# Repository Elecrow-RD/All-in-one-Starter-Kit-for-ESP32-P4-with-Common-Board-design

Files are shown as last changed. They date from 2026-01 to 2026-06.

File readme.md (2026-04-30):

### 1, Product picture



### 2, Product version number

| | Hardware | Software | Remark |
| ---- | --- | --- | --- |
| 1 | V1.0 | V1.0 | old |
| 2 | V1.1 | V1.1 | latest |

Differences between versions:

**V1.0**: This version uses a 360° servo.

**V1.1**: This version uses a 180° servo.

Use the corresponding code in Lesson 8.

### 3, product information

| Main Processor（ESP32-P4） | |
| --- | --- |
| CPU/SoC | 32-bit RISC-V dual-core processor up to 360 MHz for HP system;32-bit RISC-V single-core processor up to 40 MHz for LP system |
| System Memory | 16 MB (OPI/HPI)³  in-Package PSRAM |
| Storage | 128 KB HP ROM、16 KB LP ROM |
| Development language | C/C++ Language |
| **Display** | |
| Size | 7inch |
| Resolution | 1024*600 |
| Touch Type | Capacitive |
| Panel Type | IPS |
| **Wireless Communication** | |
| Bluetooth | Not supported |
| WiFi | Not supported |
| Wireless communication expansion | Support can be used with [wireless module](https://www.elecrow.com/wireless-module-for-crowpanel-advanced-series.html) |
| Camera | 2 MegaPixels,100° wide-angle |
| **Hardware** | |
| Interface | 1x TYPE-C Interface,1x I/C(ZX-HY2.0-4PZZ), 1x UART(ZX-HY2.0-4PZZ), 1xI/O(20P*2,P=2.54mm), 1xCSI, 1xUSB, 1x Ethernet,1x TF Card Slot |
| Button | Rest Button |
| LED Indicator | I/O port working status indicator light |
| **Other** | |
| Size | 195\*170*46（mm） |
| Material | PP Plastic |
| Input | 5v |
| Weight | 600g |

### 4, Use the driver module

| Name | dependency library |
| ---- | --- |
| LVGL | lvgl/lvgl@8.3.3 |

### 5,Quick Start
##### Arduino IDE starts

1.Download the library files used by this product to the 'libraries' folder.

C:\Users\Documents\Arduino\libraries\



2.Open the Arduino IDE

7739691367693(1)

3.Open the code configuration environment and burn it



##### ESP-IDF starts

1.Right-click on an empty space in the project folder and select "Open with VS Code" to open the project.


2.In the IDF plug-in, select the port, then compile and flash



### 6,Folder structure.
|--3D file： Contains 3D model files (.stp) for the hardware. These files can be used for visualization, enclosure design, or integration into CAD software.

|--Datasheet: Includes datasheets for components used in the project, providing detailed specifications, electrical characteristics, and pin configurations.

|--Eagle_SCH&PCB: Contains **Eagle CAD** schematic (`.sch`) and PCB layout (`.brd`) files. These are used for circuit design and PCB manufacturing.

|--example: Provides example code and projects to demonstrate how to use the hardware and libraries. These examples help users get started quickly.

|--factory_firmware: Stores pre-compiled factory firmware that can be directly flashed onto the device. This ensures the device runs the default functionality.

|--factory_sourcecode:  Contains the source code for the factory firmware, allowing users to modify and rebuild the firmware as needed.

|--libraries: Includes necessary libraries required for compiling and running the project. These libraries provide drivers and additional functionalities for the hardware.

### 7,Pin definition
1，Ultrasonic Sensor：



2，LIGHT SENSOR



3，LED



4,Temperature & Humidity(DHT20)



5,DSI



6.PIR

IO24；

7.Servo Motor

IO25;

8,Accelerometer & Gyro



9,HALL SENSOR

IO7;

10,Custom key

IO16;



11,Touch Sensor

IO2;

12,MIC



13,Audio Interface



14,GAS-MQ2

IO17;

15,Relay

IO42;

16,CSI Interface



17,Wireless module



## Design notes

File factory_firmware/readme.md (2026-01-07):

# How to install the factory demo firmware with flash download tool?

#### 1.Preparation:

- USB C cable
- Laptop/PC
- Crowpanel Advance HMI ESP32 AI Display
- Flash download tool

Check whether the materials on the PCBA board are defective. Such as less material, false welding, tin and other bad phenomena.

#### 2.Flash the firmware 

##### Step1 Connect the ESP32 P4 to the laptop/PC with USB-C cable. The power indicator will light up.

##### Step2 Open the flash download tool. 

flash02

For the  Crowpanel Advance HMI ESP32 AI Display, the chip select ESP32-P4:



##### Step3

①Choose the firmware files;

②Enter the address: 

bootloader-0x2000.bin-------0x2000

esp32p4_dev_kits_ui-0x10000.bin----0x10000

partition-table-0x8000.bin-----0x8000

storage-0x910000.bin-------0x910000

③Check the firmware files;

④Select the correct port number;

⑤Click “Start” to download

##### Step5 After the download is complete, blue FINISH will be displayed, and the progress bar at the bottom shows that it has come to an end.

##### Step6 Press the reset button to show the demo.

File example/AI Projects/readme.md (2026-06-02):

All-in-one_Starter_Kit_for_ESP32-P4_AI Demo User Guide
Preparation tools:
All-in-one Starter Kit for ESP32-P4 with Common Board



Wireless Module ESP32-C6:



USB cable:



VS Code (ESP-IDF v5.5.3 installed)



Download the code for the P4 kit:
Download the code for the corresponding screen size:

https://github.com/Elecrow-RD/All-in-one-Starter-Kit-for-ESP32-P4-with-Common-Board-design/tree/master/example/AI%20Projects/ESP-IDF_Code

Use VS Code to open the project:
1. Open VS Code and choose to open the project folder.



2. Select the folder you want to open, click “Select Folder” to open the project. Be careful not to double-click to open it.



3. Connect the device to the computer. Connect the device side to the UART0 port and plug it into the computer’s COM port.



4. Select ESP-IDF v5.4.2.



5. Select the flashing method.



6. Select the COM port.



7. Select the flashing development board – esp32p4.



8.Before flashing, you can choose to clear the previous “build” cache. This step is not necessary, but you can choose to clear it. If you have modified the code, clearing the previous cache will improve the compilation success rate.



9. Compile the project. Please make sure the network connection is good. The compilation process may take some time, so please wait patiently.



This means the compilation is successful:



10. Click to flash to the P4 HMI development board.



Once the download is complete, start configuring the **Wi-Fi**:



① Connect your phone to the Wi-Fi network named “Xiaozhi-A0B5.” You will be automatically redirected to the Wi-Fi settings page. Enter the password for the Wi-Fi network you want to connect to, tap “Connect,” and the Wi-Fi setup is complete.



② A message indicating that the configuration was successful will appear.



11. After flashing is completed, when the device connects to Wi-Fi, the screen will display the verification code for connecting the device:



12. On the computer, log in to the “xiaozhi.me” website to configure the device, and first set it to the English version.



13. Click “Console” to enter the console.



14. Click “Add Device” to add a device.



15. Enter the device code, then click “Confirm”. Note that the device code here must be based on the output displayed on your own device.



16. Select “Open Source” and click “Start Using”.



17. Now your AI device can already chat. Since the default language is Chinese, we also need to configure the role. Click “Configure Role”.



18. Set “Dialogue Language” to “English”.



19. Save the configuration.



20. Next, we set the wake word. First, go back to “Agents”.



21. Select “Manage Devices”.



22. Select “Customize”, then choose “English”, and click “Next” to enter the next configuration step.



23. In “Select Wake Word”, choose your wake word, or you can select “No Wake Word” if you do not want a wake word.
Note: Here you can also choose to customize the emojis you need by selecting “Emoji Collection”. Otherwise, there will be no emojis. You also need to select a preset font; otherwise, the dialogue text will not be fully displayed.



24. After selecting, click “Next”.



25. Click “Generate assets.bin”.



26. Start Generate.



27. Click “Flash to Device Online” to perform the remote update. After the update is completed, you can use the new wake word to wake up the device.



28. During the update process, please do not disconnect the device from power or the network.



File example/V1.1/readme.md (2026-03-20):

## IDF

**Note**: This is an IDF course. Before proceeding, ensure you have **Visual Studio Code** and the **IDF **environment installed. The IDF version must be **5.4.2** or higher.

## Arduino

**Note**: In this Arduino example, the ESP32 is running **version 3.3.3**, and the library versions used are as follows:

ESP32Servo 3.1.3
ESP32_Display_panel 1.0.4
ESP32_IO_Expander 1.1.1
esp-lib-utils 0.3.0
ESP32_Display_panel 1.0.4
HCSR04 2.0.0
Adafruit_BusIO 1.17.4
lvgl 8.3.11
Adafruit NeoPixel 1.15.1

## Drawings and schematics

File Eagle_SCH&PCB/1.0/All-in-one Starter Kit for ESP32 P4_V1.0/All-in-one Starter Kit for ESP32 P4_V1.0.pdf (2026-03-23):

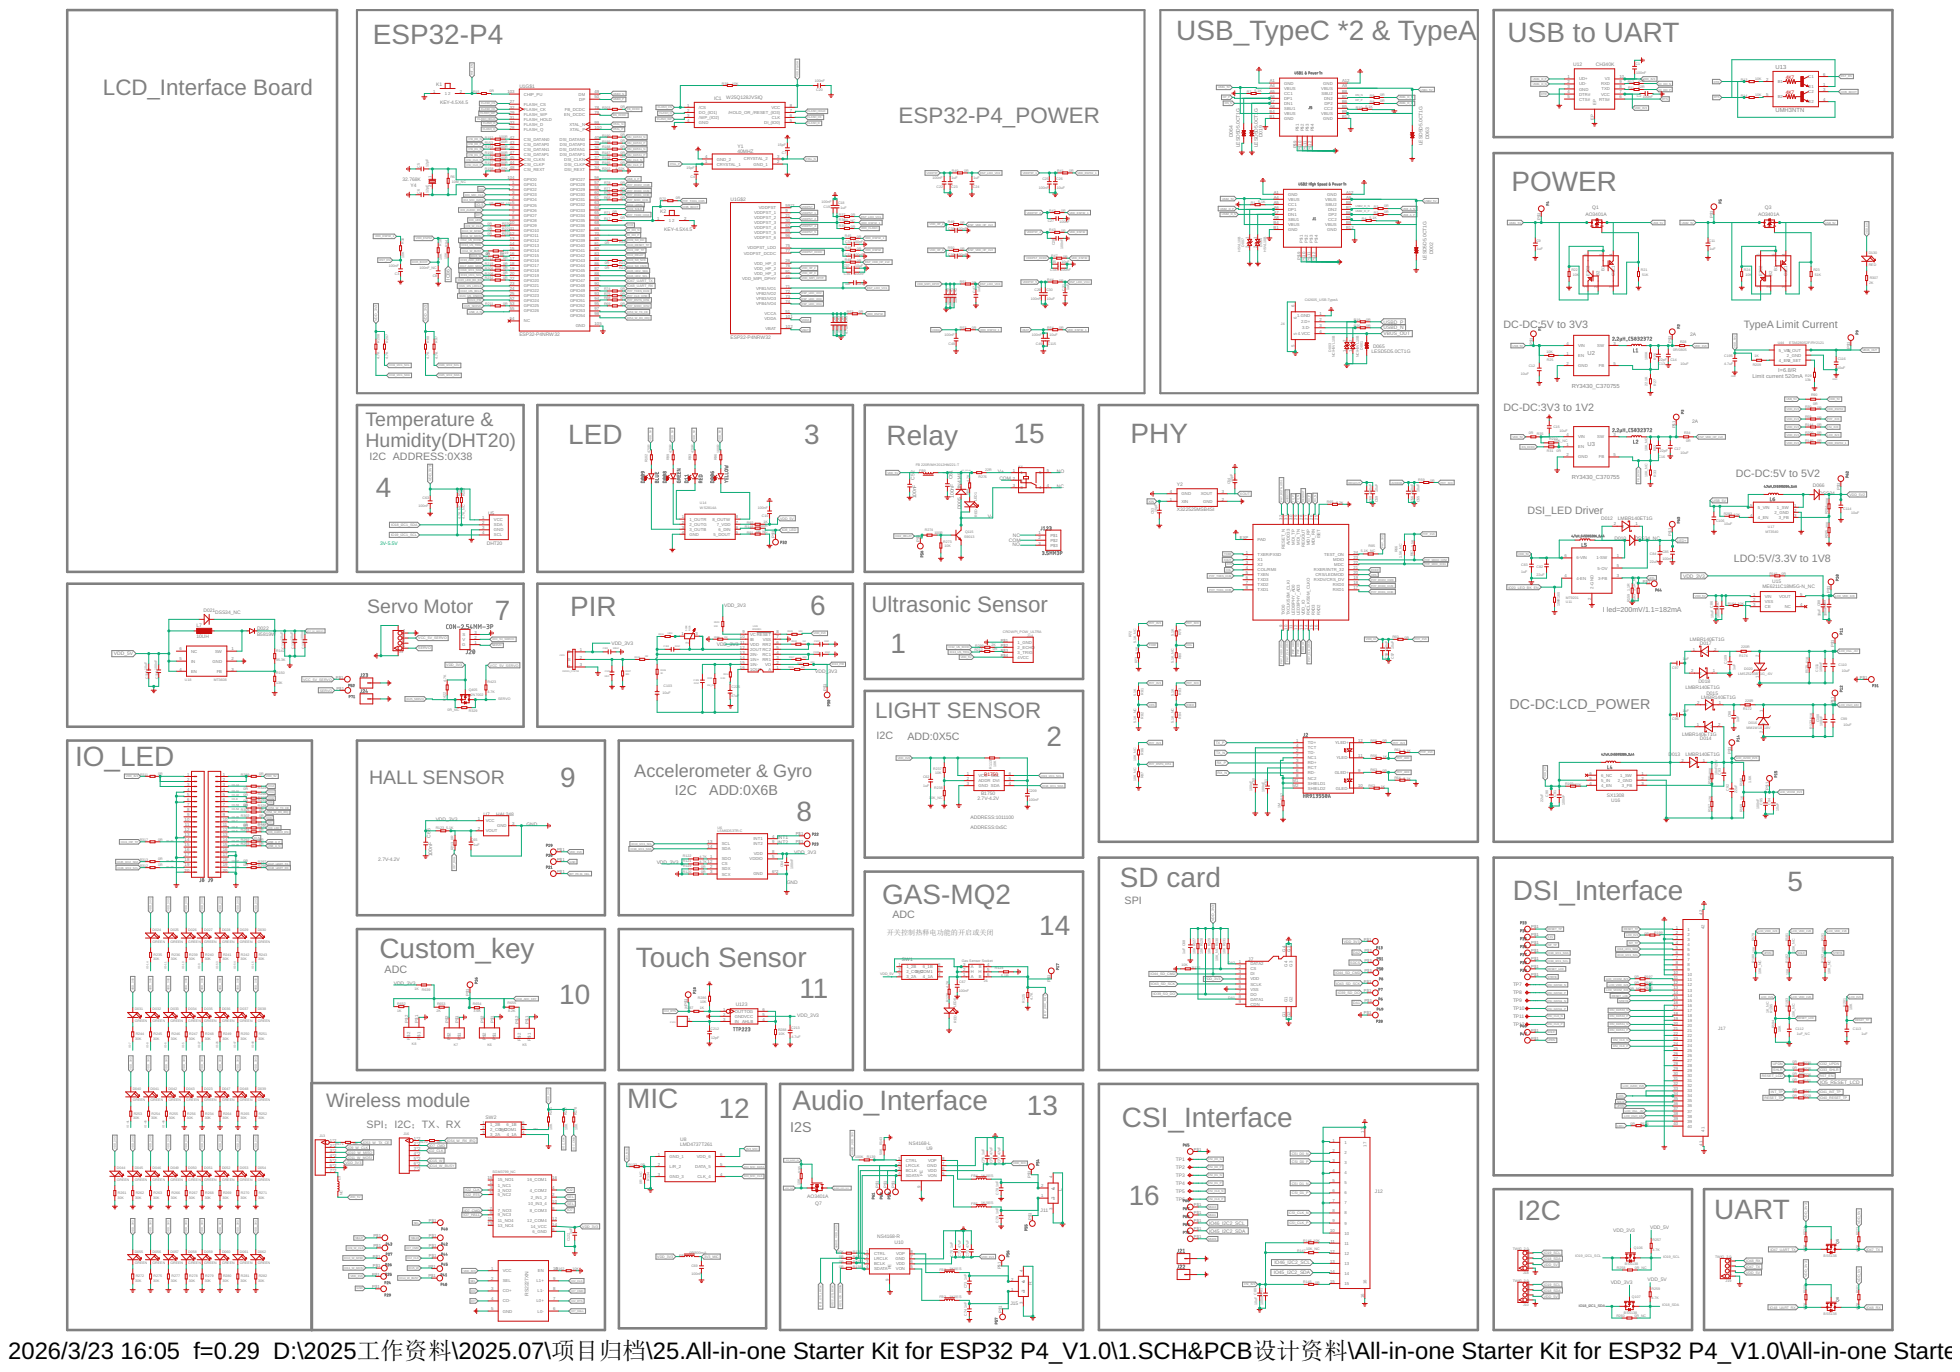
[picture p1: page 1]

2026/3/23 16:05 f=0.29 D:\2025工作资料\2025.07\项目归档\25.All-in-one Starter Kit for ESP32 P4_V1.0\1.SCH&PCB设计资料\All-in-one Starter Kit for ESP32 P4_V1.0\All-in-one Starter Kit for ESP32 P4_V1.0.sch (Sheet: 1/1)

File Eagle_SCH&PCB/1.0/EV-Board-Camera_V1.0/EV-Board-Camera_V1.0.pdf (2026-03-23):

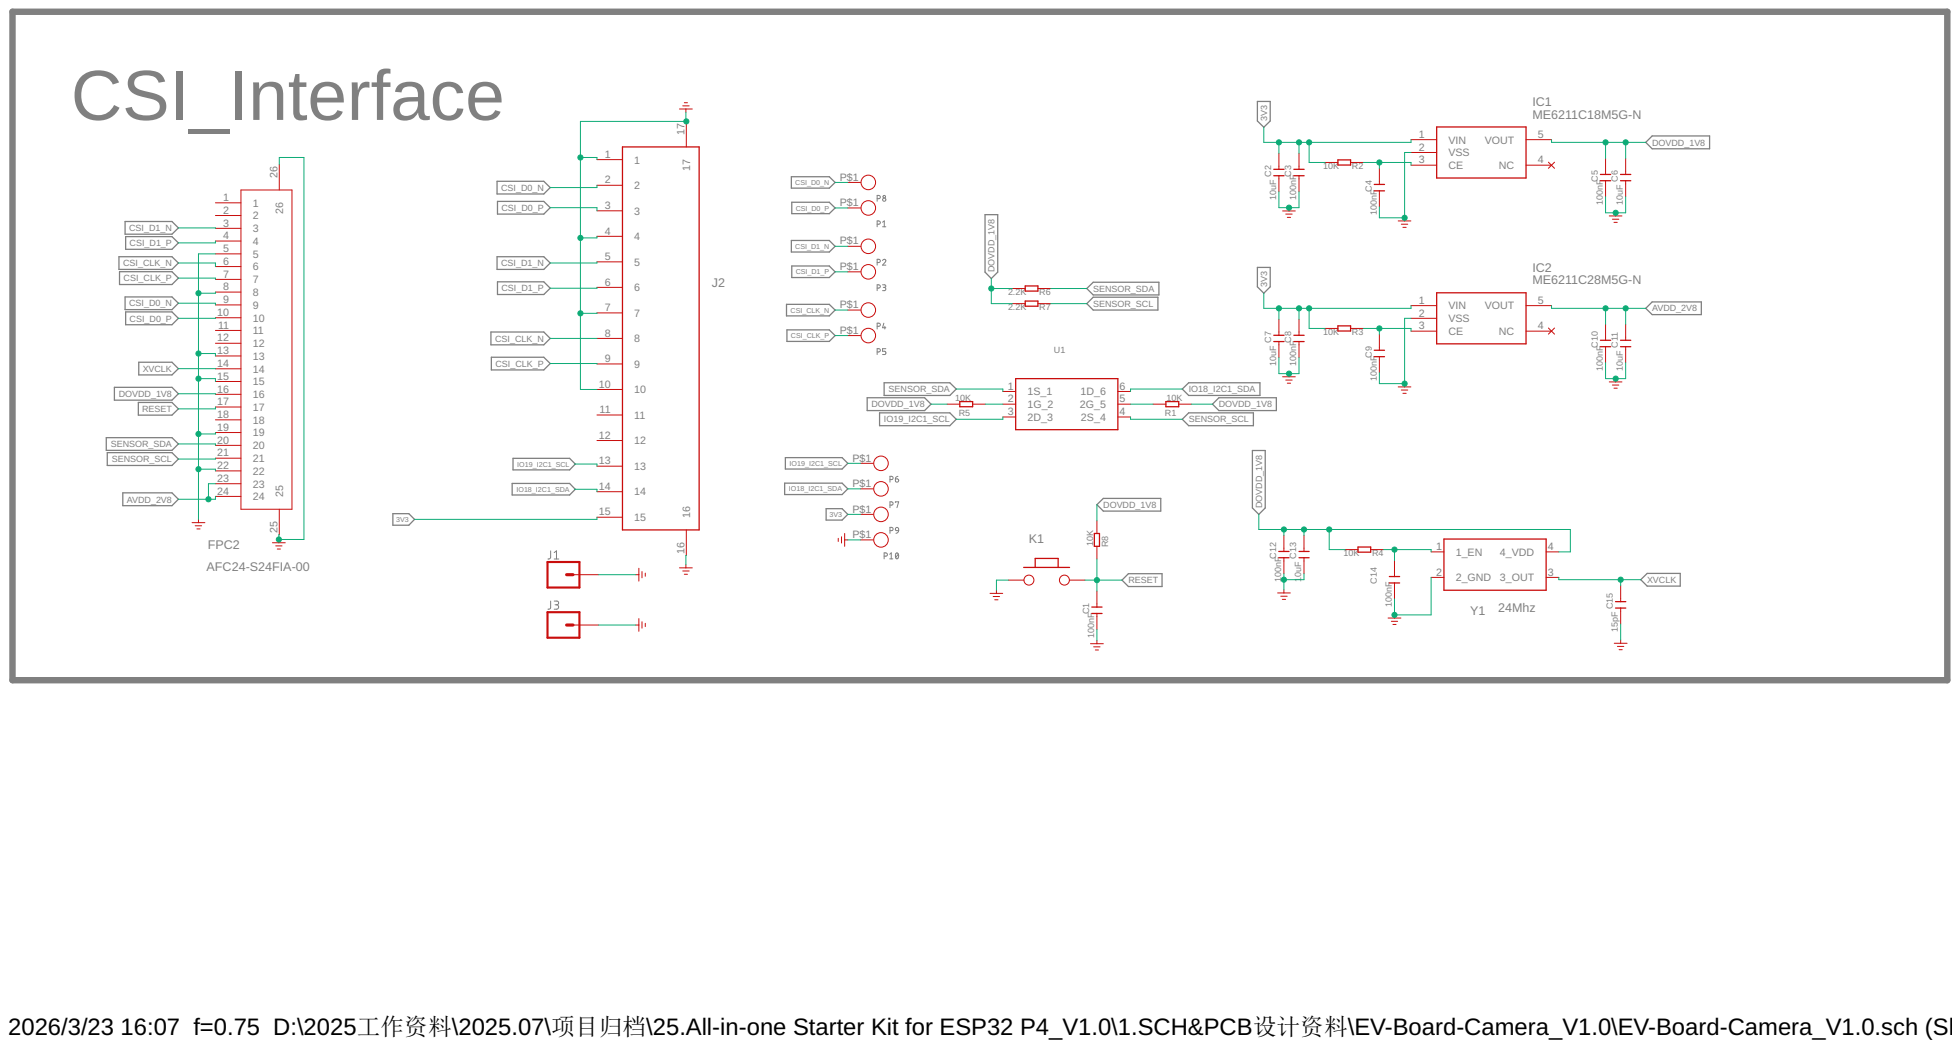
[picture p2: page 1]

2026/3/23 16:07 f=0.75 D:\2025工作资料\2025.07\项目归档\25.All-in-one Starter Kit for ESP32 P4_V1.0\1.SCH&PCB设计资料\EV-Board-Camera_V1.0\EV-Board-Camera_V1.0.sch (Sheet: 1/1)

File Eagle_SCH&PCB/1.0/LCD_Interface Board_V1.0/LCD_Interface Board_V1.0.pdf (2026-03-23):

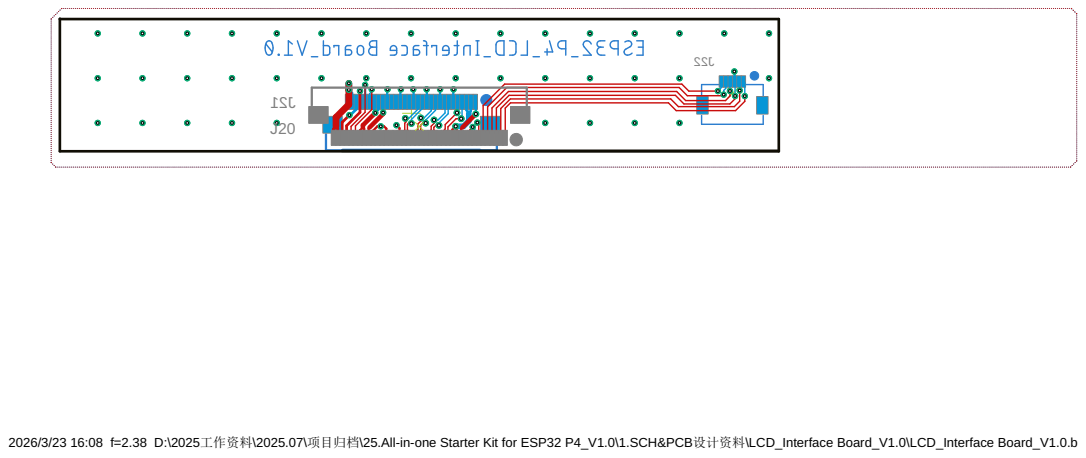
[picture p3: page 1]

2026/3/23 16:08 f=2.38 D:\2025工作资料\2025.07\项目归档\25.All-in-one Starter Kit for ESP32 P4_V1.0\1.SCH&PCB设计资料\LCD_Interface Board_V1.0\LCD_Interface Board_V1.0.brd

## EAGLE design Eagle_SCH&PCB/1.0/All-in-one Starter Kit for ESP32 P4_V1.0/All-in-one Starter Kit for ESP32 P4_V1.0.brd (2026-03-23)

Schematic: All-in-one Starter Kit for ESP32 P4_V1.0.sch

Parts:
C1, C2, C3, C10, C19, C20, C22, C25, C27, C28, C29, C32, C33, C34, C36, C38, C39, C41, C44, C46, C48, C49, C50, C51, C52, C56, C58, C60, C61, C63, C64, C66, C67, C69, C81, C85, C87, C89, C91, C95, C100, C102, C111, C118, C121, C209: 100nF; 0603
C4, C7: 15pF; 0603
C5, C6: 12pF; 0603
C8: 100nF_NC; 0603
C9, C11, C18, C21, C23, C24, C31, C42, C47, C65, C70, C75, C96, C97, C98, C109, C113, C122: 1uF; 0603
C12, C14, C15, C17, C26, C30, C35, C37, C55, C57, C59, C80, C86, C88, C94, C99, C103, C106, C110, C114, C115, C116: 10uF; 0603
C13, C16: 22pF; 0603
C40, C43: 10nF; 0603
C45, C195, C213: 4.7uF; 0603
C53, C54: 15pF; C0603
C62, C68, C83: 1uF; C0603
C71, C72, C76, C77: 47uF; 0603
C73, C74, C78, C79: 1nF; 0603
C82, C84, C90, C92: 22uF; C0805
C93: 10nF/25V; 0603
C101, C107, C108: 10nF; C0603
C104, C105: 22nF; C0603
C112: 1uF_NC; 0603
C117, C119, C120: 10uF; C0603
C212: 12pF; C0603
C225: 47uF; C0805
D001, D003: NC/H5VL10B; H5VL10B
D002, D019, D063, D064, D065: LESD5D5.0CT1G; TVS_LESD5D5.0CT1G
D004, D007: H5VL10B
D005: 1N4148; D_SOD123
D006: YELLOW; LED-8MM
D008: GREEN; LED-8MM
D009: BLUE; LED-8MM
D010, D021: DSS34_NC; D_SOD123FL
D11: RED; LED-8MM
D012, D013, D014, D015, D017, D018: LMBR140ET1G
D016: MM1W18_18V; LMSZ5233BT1G
D020: LMSZ5233BT1G_-6V; LMSZ5233BT1G
D022: B5819W; SOD-123_MINI-SMA
D023, D024, D025, D026, D027, D028, D029, D030, D031, D032, D033, D034, D035, D036, D037, D038, D039, D040, D041, D042, D043, D044, D045, D046, D047, D048, D049, D050, D051, D052, D053, D054, D055, D056, D057, D058, D059, D060, D061, D062: GREEN; LED_0603_SMT
D066: DSS34; D_SOD123FL
D130: RED; LED_0603_SMT
FB1: 0R/800mA; L0603
FB2, FB3, FB4, FB5: 1K/磁珠; L0603
FB9: FB 220R/MH2012HM221-T; L0805
IC1: W25Q128JVSIQ; SOIC127P790X216-8N
J1: USB2 High Speed & Power in; WZ3532R024-ESP32-V0.1-20221226_KEVIN_3.0TYPEC-SMD
J2: HR913550A; LORA_BASIC_GATEWAY_-MODULE_HR911105A-RJ45
J3: A_XBJ_CONNECTOR_TWIG-4P-2.0-SMD-FEMALE-REINFORCE9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; A_XBJ_CONNECTOR_4P-SMD-2.0-90D
J4: C42605_USB-TypeA; C42605/USB2.0
J5: USB1 & Power in; WZ3532R024-ESP32-V0.1-20221226_KEVIN_3.0TYPEC-SMD
J6: Gas Sensor Socket; MQ2
J7: HOLDER-MICROSD-9P; 9P-SMD-W/-RING
J8, J9: CONN_20; 1X20
J10, J18, J19: TWIG_2.0; 2.0_1X4
J11: L; 1X02L
J12: C262349_15P_1MM_下接_AFA07-S15FCC-00
J13, J16: HEADER-7P-18.28X2.5; H7-2.54-18.28X2.5X5MM
J14: CROWPI_POW_ULTRA
J15: R; 1X02L
J17: C19273935_40P_0.5MM_下接_HC-FPC-0.5-40P-FH20
J20: CON-2.54MM-3P; CON-PZ-2.54MM-1*3P-WT
J21, J22: CONN_01_3.1MM_SMD1X01_3.1MM_SMD; 1X01_2MM
J23, J24: CONN_01_2.6MM1X01_2.6-4MM; 1X01_2.6MM
J101: D203S_C78793; 3P-D8.1MM
J123: 3.5MM3P; 3.5MM*3P
K1, K2: KEY-4.5X4.5; KEY-4.5X4.5-SMD
K4: RELAY-SRD; REY5-6-19.1X15.5X15.3MM
K5, K6, K7, K8: BUTTON_2P
L1, L2: 2.2μH_C5832372; 1008(2520)
L3: NC; L0603
L4, L5, L6: 4.7uH_C45385206_2.4A; 1008(2520)
L7: 10UH; SMD-4X4MM
LED1, LED6: RED; DISCRETE_LED-0603
P1, P2, P3, P4, P5, P6, P7, P8, P9, P10, P11, P12, P13, P14, P15, P16, P17, P18, P19, P20, P21, P22, P23, P24, P25, P26, P27, P28, P29, P30, P31, P32, P33, P34, P35, P36, P37, P38, P39, P40, P41, P42, P43, P44, P45, P46, P47, P48, P49, P50, P51, P52, P54, P55, P56, P57, P58, P59, P60, P61, P62, P63, P64, P65, P66, P67, P68, P69, P70, P71: TEST_PADPAD-1.5MM; TEST_PAD-1.5MM
P101: KEY; 1P-D450
Q1, Q3, Q7: AO3401A; SOT23-3
Q2, Q4: LMBT3906DW1T1G
Q5, Q6, Q106, Q107: BSS138; SOT23
Q115: S9013; SOT23@1
Q405: 2N7002; SOT23
R1, R4, R7, R10, R61, R64, R73, R79, R81, R83, R123: 5.1K; R0603
R2, R3, R5, R8, R9, R15, R17, R19, R20, R30, R31, R34, R35, R37, R39, R40, R41, R42, R43, R44, R45, R46, R47, R48, R49, R50, R51, R52, R53, R54, R55, R58, R59, R60, R63, R68, R69, R70, R71, R74, R75, R76, R77, R78, R88, R118, R119, R120, R133, R140, R141, R144, R145, R151, R176, R185, R186, R187, R188, R189, R190, R196, R197, R199, R200, R203, R205, R206, R211, R212, R213, R214, R215, R216, R217, R219, R220, R221, R222, R225, R227, R228, R230, R231, R232, R289, R290, R291, R292, R293, R294, R295, R296, R297, R298, R302, R305, R311, R312, R313, R315, R317, R324, R328, R332: 0R; R0603
R6: 10M_NC; R0603
R11, R12, R276: 22R; R0603
R13, R14, R16, R18, R22, R24, R25, R38, R94, R95, R107, R109, R112, R113, R115, R117, R146, R149, R161, R162, R164, R177, R178, R179, R182, R191, R194, R201, R237, R273, R283, R286, R288: 10K; R0603
R21, R23, R173, R175: 51K; R0603
R26, R165, R284: 100K; R0603
R27: 22.1K; R0603
R28: 0R/0805; R0805-SP
R29: 13k; R0603
R32, R33, R86, R87, R147, R180, R181, R192, R193, R210, R238: 10K_NC; R0603
R36, R91, R134, R198, R226, R258, R260, R329: 0R_NC; R0603
R56, R62, R92, R106, R169, R209, R287, R639, R652: 1K; R0603
R57, R108, R110: 1M; R0603
R65: 6.2K; R0603
R66: 1.5K_NC; R0603
R67: 1.5K; R0603
R72, R80, R82, R84, R85: 5.1K_NC; R0603
R89, R97, R98, R121, R122, R125, R126, R207, R208, R257, R259, R422, R423: 4.7K; R0603
R90: 0R; R0805-SP
R93, R99, R102: 470R; R0603
R96, R148, R152, R153, R154, R155, R156, R157, R274: 100R; R0603
R100, R101, R223, R224: 4.7K; R0603-SP
R103, R104: 4.7K_NC; R0603
R105: 500K; 3P-SMD-SQUA-3.6X3.3
R111: 1M_1%; R0603
R114: 3.3K; R0603
R116: 130K; R0603
R124: 5.1R; R0603
R127, R128, R129, R131, R132, R160: 10K; R0603-SP
R130: 10K_NC; R0603-SP
R135, R139: 100K; R0603-SP
R136, R137, R138, R170, R171: 0R; R0603-SP
R142: 95.3K; R0603
R143: 50K; R0603-SP
R150: 13K; R0603
R158, R202: 4.02K; R0603
R159: 1.1R; R0603-SP
R163: 1.1R_NC; R0603-SP
R166: 180K; R0603
R167: 12K; R0603
R168: 1.6K; R0603
R172, R174: 220R; R0603
R195: 1K_NC; R0603
R234, R235, R236, R239, R240, R241, R242, R243, R244, R245, R246, R247, R248, R249, R250, R251, R252, R253, R254, R255, R256, R261, R262, R263, R264, R265, R266, R267, R268, R269, R270, R271, R272, R275, R277, R278, R279, R280, R281, R282, R285: 30K; R0603
R299, R307, R653: 2K; R0603
R654: 3.6K; R0603
R655: 8.2K; R0603
SW1, SW2: switch_6pin; SWITCH_6PIN_2P
TP1, TP2, TP3, TP4, TP5, TP6, TP7, TP8, TP9, TP10, TP11, TP12: TPTP08R; TP08R
U1: ESP32-P4NRW32; IC_ESP32-P4NRW32
U2, U3: RY3430_C370755; SOT95P280X145-5N
U4: IP101GR; QFN32_4X4
U5: DHT20; CROWTAIL-DHT20-V1.0-20211013_DHT20
U6: LSM6DS3TR-C; LGA-14L
U7: HAL248; SOT-23W
U8: LMD4737T261; MIC_LMD4737T261
U9: NS4168-L; NS4168-ESOP-8
U10: NS4168-R; NS4168-ESOP-8
U11: MT9201; COOPER_SOT23-6
U12: CH340K; ESOP-10-EP-150MIL
U13: UMH3NTN; SOP65P210X100-6N
U14: WS2814A
U15: ME6211C18M5G-N_NC; SOT95P282X145-5N
U16: SX1308; SOT95P280X145-6N
U17: MT3540; SOT95P280X145-5N
U18: MT3608; DBV_R-PDSO-G6
U19: SGM3799_NC; IC_SGM3799_TQFN2.6X1.8_16L
U44: ETA6280S2F/RY2121; IC_SOT23-5
U101: BIS0001; SOP16
U121: BH1750; B1750
U123: TTP223; SOT23-6L
U$196: MSOP10
Y1: 40MHZ; X322540MPB4SI
Y2: X322525MSB4SI; SMD3225
Y4: 32.768K; NORDIC_NRF_XTAL_3215_N

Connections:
3.3V: J17.2, P34.P$1, R199.2
3V3_MIC: C69.2, FB1.2, R133.1, U8.6 (VDD_6)
+5V_SYS_GAS: C67.2, J6.1 (A), J6.2 (H), J6.3 (A), R126.2, SW1.2 (2_COM2)
AUDIO_VDD_3V3: Q7.3 (3_D), R135.2, R139.2
AVDD33: C55.2, C56.2, R59.1, U4.31 (AVDD33)
BIT_P0.31_HAL: C65.1, P21.P$1, R123.1, R213.1, U7.2 (VOUT)
CLK_N: R186.2, U1.37 (DSI_CLKN)
CLK_P: R185.2, U1.38 (DSI_CLKP)
COL: R79.1, R80.2, U4.4 (COL/RMII)
COM: J123.2, K4.2
CRS: R81.1, R82.2, U4.20 (CRS/LEDMOD)
CSICLK_N: R156.1, U1.45 (CSI_CLKN)
CSICLK_P: R157.1, U1.44 (CSI_CLKP)
CSID0_N: R152.1, U1.42 (CSI_DATAN0)
CSID0_P: R153.1, U1.43 (CSI_DATAP0)
CSID1_N: R154.1, U1.46 (CSI_DATAN1)
CSID1_P: R155.1, U1.47 (CSI_DATAP1)
CSI_3V3: C80.1, C81.1, R144.2, R145.1, R146.1, R147.1
CSI_CLK_N: J12.8, R156.2, TP5.TP
CSI_CLK_P: J12.9, R157.2, TP6.TP
CSI_D0_N: J12.2, R152.2, TP1.TP
CSI_D0_P: J12.3, R153.2, TP2.TP
CSI_D1_N: J12.5, R154.2, TP3.TP
CSI_D1_P: J12.6, R155.2, TP4.TP
DA1: J7.8 (DATA1), P49.P$1, R127.1
DA2: J7.1 (DATA2), P51.P$1, R131.1
DATA0_N: R190.2, U1.40 (DSI_DATAN0)
DATA0_P: R189.2, U1.39 (DSI_DATAP0)
DATA1_N: R188.2, U1.36 (DSI_DATAN1)
DATA1_P: R187.2, U1.35 (DSI_DATAP1)
DN_N: D019.2, J5.A7 (DN1), J5.B7 (DN2), R9.2
DP_P: D064.2, J5.A6 (DP1), J5.B6 (DP2), R8.2
DSI_CLK_N: J17.23, R186.1, TP11.TP
DSI_CLK_P: J17.24, R185.1, TP12.TP
DSI_DATA0_N: J17.17, R190.1, TP7.TP
DSI_DATA0_P: J17.18, R189.1, TP8.TP
DSI_DATA1_N: J17.20, R188.1, TP9.TP
DSI_DATA1_P: J17.21, R187.1, TP10.TP
DTR: R13.2, U12.4 (DTR#), U13.4 (E2)
EN_DCDC: R31.2, U1.79 (EN_DCDC)
ESP_LDO_VO1: C21.2, R37.2, U1.71 (VFB1/VO1)
ESP_LDO_VO2: C24.1, R40.2, U1.72 (VFB2/VO2)
ESP_LDO_VO3: C47.2, R51.2, U1.73 (VFB3/VO3)
ESP_LDO_VO4: C31.2, R44.2, U1.74 (VFB4/VO4)
ESP_VDD_HP_1V2: R34.2, R48.2, R49.2, R50.2
FB_DCDC: C16.1, R32.2, R33.1, R203.1, U3.5 (FB)
FLASH_CK: IC1.6 (CLK), U1.32 (FLASH_CK)
FLASH_CS: IC1.1 (/CS), R38.1, U1.27 (FLASH_CS)
FLASH_D: IC1.5 (DI_(IO0)), U1.33 (FLASH_D)
FLASH_HOLD: IC1.7 (/HOLD_OR_/RESET_(IO3)), U1.31 (FLASH_HOLD)
FLASH_Q: IC1.2 (DO_(IO1)), U1.28 (FLASH_Q)
FLASH_WP: IC1.3 (/WP_(IO2)), U1.29 (FLASH_WP)
GND: C1.2, C2.1, C3.2, C4.2, C5.2, C6.2, C7.1, C8.2, C9.1, C10.1, C11.1, C12.2, C14.1, C15.2, C17.1, C18.2, C19.1, C20.2, C21.1, C22.2, C23.2, C24.2, C25.2, C26.1, C27.2, C28.2, C29.2, C30.1, C31.1, C32.2, C33.2, C34.2, C35.1, C36.2, C37.1, C38.2, C39.2, C40.2, C41.2, C42.2, C43.2, C44.2, C45.2, C46.2, C47.1, C48.2, C49.2, C50.1, C51.1, C52.1, C53.2, C54.1, C55.1, C56.1, C57.1, C58.1, C59.1, C60.1, C61.1, C62.1, C63.1, C64.1, C65.2, C66.1, C67.1, C68.1, C69.1, C70.2, C71.2, C72.2, C73.1, C74.1, C75.2, C76.2, C77.2, C78.1, C79.1, C80.2, C81.2, C82.2, C83.1, C84.2, C85.1, C86.2, C87.2, C88.2, C89.2, C90.2, C91.2, C92.2, C94.2, C95.2, C98.2, C99.2, C100.2, C101.1, C102.1, C106.1, C107.2, C108.2, C109.2, C110.2, C111.2, C112.2, C113.2, C114.1, C115.2, C116.2, C117.1, C118.1, C119.1, C120.1, C121.1, C122.1, C195.2, C209.1, C212.1, C213.1, C225.1, D001.1, D002.1, D003.1, D004.2, D007.2, D016.2, D018.1, D019.1, D020.1, D063.1, D064.1, D065.1, IC1.4 (GND), J1.A1 (GND), J1.A12 (GND), J1.B1 (GND), J1.B12 (GND), J1.P$9, J1.P$10, J1.P$11, J1.P$12, J3.4, J3.SS1, J3.SS2, J4.1 (1.GND), J4.5, J4.6, J5.A1 (GND), J5.A12 (GND), J5.B1 (GND), J5.B12 (GND), J5.P$9, J5.P$10, J5.P$11, J5.P$12, J7.6 (VSS), J7.G1, J7.G2, J7.G3, J7.G4, J8.4, J8.5, J8.6, J8.13, J8.17, J8.20, J9.16, J9.17, J9.20, J10.1, J11.3, J11.4, J12.1, J12.4, J12.7, J12.10, J12.16, J12.17, J13.6, J13.6-6 (6), J14.P$1 (1_GND), J15.3, J15.4, J17.3, J17.7, J17.8, J17.9, J17.10, J17.16, J17.19, J17.22, J17.25, J17.28, J17.31, J17.41, J17.42, J18.1, J19.1, J20.3 (S), J21.1, J22.1, J23.1, J24.1, J101.3 (G), K1.1, K2.2, K5.P$1, K6.P$1, K7.P$1, K8.P$1, LED6.-, P20.P$1, P28.P$1, P29.P$1, P31.P$1, P65.P$1, Q115.2 (E), R1.2, R4.1, R7.2, R10.1, R21.1, R22.1, R23.1, R24.1, R27.2, R29.2, R33.2, R57.1, R62.2, R64.2, R65.2, R73.1, R80.1, R82.1, R84.1, R87.1, R91.1, R107.1, R108.1, R119.1, R120.1, R124.1, R125.2, R132.2, R134.1, R143.1, R150.2, R158.2, R159.1, R160.2, R162.1, R163.1, R167.1, R169.1, R173.1, R175.1, R180.1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
IN1: C212.2, P101.1, U123.3 (IN)
INT1: P22.P$1, U6.4 (INT1)
INT2: P23.P$1, U6.9 (INT2)
INT_TP: J17.4, P35.P$1, R227.2
IO2: U1.2 (GPIO2), U19.4 (4_COM2), U$196.3 (CO+)
IO2_CLK: J16.3, J16.3-3 (3), P45.P$1, R177.1, U19.3 (3_NO2), U$196.9 (L1+)
IO2_RTS: P18.P$1, R287.2, U19.5 (5_NC2), U$196.7 (L0+)
IO3_MIC_CLK: U1.3 (GPIO3), U8.4 (CLK_4)
IO4_MIC_DATA: U1.4 (GPIO4), U8.5 (DATA_5)
IO5_RESET_LCD: R151.1, R231.2, U1.5 (GPIO5)
IO6_AUDIO_EN: Q7.1 (1_G), R95.1, R294.1, U1.6 (GPIO6)
IO7: R315.2, U1.7 (GPIO7), U19.8 (8_COM3), U$196.4 (CO-)
IO7_CMD: J16.2, J16.2-2 (2), P44.P$1, R178.1, U19.7 (7_NO3), U$196.8 (L1-)
IO7_HALL: R213.2, U19.9 (9_NC3), U$196.6 (L0-)
IO8_LED: P32.P$1, R148.1, R290.2, U1.8 (GPIO8)
IO9: R220.2, R291.2, U1.10 (GPIO9)
IO9_W_CLK: J13.2, J13.2-2 (2), P27.P$1, R220.1
IO10: R221.2, R295.2, U1.11 (GPIO10)
IO10_W_MISO: J13.3, J13.3-3 (3), P26.P$1, R221.1
IO11: R222.2, R296.2, U1.12 (GPIO11)
IO11_W_MOSI: J13.4, J13.4-4 (4), P25.P$1, R222.1
IO12_US_ECHO: R299.2, U1.13 (GPIO12)
IO13_US_TRIG: R212.2, U1.14 (GPIO13)
IO14: R219.2, R324.2, U1.15 (GPIO14)
IO14_W_BUSY: J16.6, J16.6-6 (6), P40.P$1, R219.1
IO15: R5.2, R302.1, U1.16 (GPIO15)
IO15_W: J16.5, J16.5-5 (5), P41.P$1, R5.1
IO16_ADC_KEY: P16.P$1, R214.2, R639.2, R652.2, R653.2, R654.2, R655.2
IO17_ADC_MQ2: J6.4 (B), J6.6 (B), P17.P$1, R125.1, R215.2
IO18_I2C1_SDA: J17.5, P36.P$1, Q107.2 (S), R103.2, R205.2, R208.2, R260.1, U5.2 (SDA), U6.14 (SDA), U121.4 (SDA)
IO18_SDA: J10.3, J18.3, Q107.3 (D), R259.2, R260.2
IO19_I2C1_SCL: J17.6, P37.P$1, Q106.2 (S), R104.2, R206.2, R207.2, R258.1, U5.4 (SCL), U6.13 (SCL), U121.6 (SCL)
IO19_SCL: J10.4, J18.4, Q106.3 (D), R257.2, R258.2
IO20_LED_BK_EN: R160.1, R232.2, U11.4 (4-EN)
IO21_I2S_LRCLK: R136.2, U1.23 (GPIO21)
IO22_I2S_BCLK: R137.2, U1.24 (GPIO22)
IO23_I2S_DSDIN: R138.2, U1.25 (GPIO23)
IO24_PIR: P30.P$1, R112.1, U1.52 (GPIO24)
IO25_SERVO: Q405.2 (S), R211.2, R329.2, R422.1
IO32_UPDN: R230.1, U1.63 (GPIO32)
IO33_SHLR: R225.1, U1.64 (GPIO33)
IO35_BOOT: C8.1, K2.1, R17.1, R18.1, R70.2, U13.3 (C2)
IO36: R94.2, U1.68 (GPIO36)
IO39_SD_DO: J7.7 (DO), P6.P$1, R128.1, R332.2
IO40_RESET_TP: R228.1, U1.81 (GPIO40)
IO41_INT_TP: R227.1, R317.2, U1.82 (GPIO41)
IO42_RELAY: P58.P$1, R274.2, U1.83 (GPIO42)
IO43_SD_SCK: J7.5 (SCLK), P7.P$1, R217.2
IO44_SD_CMD: J7.3 (DI), P8.P$1, R129.1, R216.2
IO45_I2C2_SDA: J12.14, P69.P$1, R98.2, R313.2, U1.87 (GPIO45)
IO46_I2C2_SCL: J12.13, P68.P$1, R97.2, R312.2, U1.88 (GPIO46)
IO47_TX: J19.3, Q5.3 (D), R223.2
IO47_UART_TX: Q5.2 (S), R224.2, R297.2, U1.89 (GPIO47)
IO48_RX: J19.4, Q6.3 (D), R101.2
IO48_UART_RX: Q6.2 (S), R100.2, R298.2, U1.90 (GPIO48)
IO53_W_TX_CE: R171.2, R328.2, U1.97 (GPIO53)
IO54_W_RX_IRQ: R170.2, R305.1, U1.98 (GPIO54)
IO-5: J9.13, R231.1, R247.2
IO-6: J9.12, R246.2, R294.2
IO-7: J9.10, R244.2, R315.1
IO-8: J9.11, R245.2, R290.1
IO-9: J9.6, R240.2, R291.1
IO-10: J9.5, R239.2, R295.1
IO-11: J9.4, R236.2, R296.1
IO-14: J9.3, R235.2, R324.1
IO-15: J9.9, R243.2, R302.2
IO-26: J9.15, R249.2, R293.2
IO-27: J9.14, R248.2, R292.2
IO-41: J8.14, R253.2, R317.1
IO-45: J8.18, R254.2, R313.1
IO-46: J8.19, R255.2, R312.1
IO-47: J9.18, R250.2, R297.1
IO-48: J9.19, R251.2, R298.1
IO-53: J9.7, R241.2, R328.1
IO-54: J9.8, R242.2, R305.2
IOT_5V: J13.7, J13.7-7 (7), L3.1
IO_DO_N: R12.1, U1.69 (GPIO37)
IO_DO_P: R11.1, U1.70 (GPIO38)
LCD_3V3: R195.2, R199.1, R200.2, R201.2
LCD_AVDD_9V6: C92.1, C93.1, D013.1, D014.2, J17.32, P14.P$1, R166.2, R168.2
LCD_VCOM_3V3: C94.1, C95.1, P15.P$1, R168.1, R169.2, R197.1, R198.1
LCD_VDD_1V8: C88.1, C89.1, P10.P$1, R141.2, R179.2, R181.2, R191.2, R193.2, R196.1, U15.5 (VOUT)
LCD_VGH_18V: C99.1, C100.1, D016.1, J17.38, P12.P$1, R172.1, R173.2
LCD_VGL_-6V: C110.1, C111.1, D020.2, J17.37, P11.P$1, R174.1, R175.2
LED+: C84.1, C85.2, D010.-, D012.1, P63.P$1, R176.1, U11.5 (5-OV)
LED-: J17.33, J17.34, P64.P$1, R159.2, R163.2, U11.3 (3-FB)
unnamed: Q3.1 (1_G), Q4.3 (C1), R23.2
unnamed: C6.1, R6.1, U1.1 (GPIO1), Y4.2
unnamed: C5.1, R6.2, U1.104 (GPIO0), Y4.1
unnamed: Q1.1 (1_G), Q2.3 (C1), R21.2
unnamed: Q2.2 (B2), Q2.5 (B1), Q2.6 (C2), R22.2
unnamed: C43.1, C44.1, C45.1, C46.1, R52.1, U1.51 (VCCA)
unnamed: Q4.2 (B2), Q4.5 (B1), Q4.6 (C2), R24.2
unnamed: J1.B5 (CC2), R4.2
unnamed: J1.A5 (CC1), R1.1
unnamed: J5.A5 (CC1), R7.1
unnamed: R12.2, U12.9 (RXD)
unnamed: R11.2, U12.8 (TXD)
unnamed: R13.1, U13.2 (B1)
unnamed: R15.1, U1.103 (CHIP_PU)
unnamed: R14.1, U13.5 (B2)
unnamed: R17.2, U1.66 (GPIO35)
unnamed: D130.2 (2_K), R307.1
unnamed: R209.1, U44.4 (4_EN)
unnamed: J2.12 (YLED+), R55.1
unnamed: R25.1, U2.1 (EN)
unnamed: L1.1, U2.3 (SW)
unnamed: C13.2, C14.2, L1.2, P2.P$1, R26.1, R28.1
unnamed: C13.1, R26.2, R27.1, U2.5 (FB)
unnamed: R31.1, R210.2, U3.1 (EN)
unnamed: L2.1, U3.3 (SW)
unnamed: C16.2, C17.2, L2.2, P3.P$1, R32.1, R34.1
unnamed: R203.2, U1.78 (FB_DCDC)
unnamed: C15.1, R35.1, R210.1, U3.4 (VIN)
unnamed: C32.1, R45.1, U1.96 (VDDPST_6)
unnamed: J2.11 (YLED-), R56.1
unnamed: J2.7 (NC1), J2.8 (NC2), J2.M1 (SHIELD1), J2.M2 (SHIELD2), R57.2
unnamed: C50.2, J2.4 (TCT)
unnamed: R74.2, U1.92 (GPIO49)
unnamed: C51.2, J2.5 (RCT)
unnamed: R75.2, U1.93 (GPIO50)
unnamed: R77.2, U1.58 (GPIO29)
unnamed: R85.1, U4.24 (TEST_ON)
unnamed: R76.2, U1.60 (GPIO30)
unnamed: R71.2, U1.65 (GPIO34)
unnamed: R78.2, U1.57 (GPIO28)
unnamed: R88.2, U1.94 (GPIO51)
unnamed: J2.10 (GLED-), R62.1
unnamed: J2.9 (GLED+), R63.1
unnamed: R68.2, U1.61 (GPIO31)
unnamed: LED1.+, R89.1
unnamed: J14.P$3 (3_TRIG), R212.1
unnamed: R232.1, U1.22 (GPIO20)
unnamed: R214.1, U1.17 (GPIO16)
unnamed: C209.2, R113.1, U121.5 (DVI)
unnamed: R91.2, U14.5 (5_DOUT)
unnamed: R69.2, U1.95 (GPIO52)
unnamed: D009.2 (C), U14.3 (3_OUTB)
unnamed: D11.1 (A), R93.2
unnamed: R65.1, U4.25 (ISET)
unnamed: D008.2 (C), U14.2 (2_OUTG)
unnamed: D11.2 (C), U14.1 (1_OUTR)
unnamed: R29.1, U44.3 (3_SET)
unnamed: D006.1 (A), R96.2
unnamed: J5.B5 (CC2), R10.2
unnamed: D006.2 (C), U14.8 (8_OUTW)
unnamed: R142.2, R150.1, U18.3 (FB)
unnamed: D008.1 (A), R99.2
unnamed: R92.2, U14.7 (7_VDD)
unnamed: D022.A, L7.2, U18.1 (SW)
unnamed: D009.1 (A), R102.2
unnamed: R117.1, U101.3 (RR1)
unnamed: C108.1, R117.2, U101.4 (RC1)
unnamed: R112.2, U101.2 (VO)
unnamed: R110.2, U101.6 (RR2)
unnamed: C107.1, R110.1, U101.5 (RC2)
unnamed: C104.2, R105.2 (3), R105.3 (2), U101.12 (2OUT)
unnamed: C104.1, R106.2, R116.2, U101.13 (2IN-)
unnamed: R109.2, U101.9 (VC)
unnamed: R108.2, U101.10 (IB)
unnamed: C101.2, J101.2 (S), R107.2, R118.2
unnamed: C103.2, C105.1, R111.1, U101.16 (1OUT)
unnamed: C105.2, R111.2, R114.2, U101.15 (1IN-)
unnamed: C103.1, R106.1
unnamed: C225.2, R114.1
unnamed: R115.2, U101.1 (A)
unnamed: R118.1, U101.14 (1IN+)
unnamed: R105.1, R116.1
unnamed: R119.2, U6.2 (SDX)
unnamed: R120.2, U6.3 (SCX)
unnamed: R121.2, U6.12 (CS)
unnamed: R122.2, U6.1 (SDO)
unnamed: J6.5 (H), R124.2
unnamed: LED6.+, R126.1
unnamed: R217.1, U1.84 (GPIO43)
unnamed: R216.1, U1.86 (GPIO44)
unnamed: R133.2, R134.2, U8.2 (L/R_2)
unnamed: R135.1, U10.1 (CTRL)
unnamed: P61.P$1, R136.1, U9.2 (LRCLK), U10.2 (LRCLK)
unnamed: P60.P$1, R137.1, U9.3 (BCLK), U10.3 (BCLK)
unnamed: P59.P$1, R138.1, U9.4 (SDATA), U10.4 (SDATA)
unnamed: FB2.1, U10.8 (VOP)
unnamed: FB3.1, U10.5 (VON)
unnamed: R332.1, U1.80 (GPIO39)
unnamed: C78.2, FB4.2, J11.2, P54.P$1
unnamed: R139.1, R143.2, U9.1 (CTRL)
unnamed: C97.2, D017.1, D018.2
unnamed: R162.2, U$196.10 (EN)
unnamed: FB4.1, U9.8 (VOP)
unnamed: FB5.1, U9.5 (VON)
unnamed: C79.2, FB5.2, J11.1, P55.P$1
unnamed: C74.2, FB3.2, J15.1, P57.P$1
unnamed: J12.15, P70.P$1, R145.2
unnamed: J12.11, P66.P$1, R146.2
unnamed: J12.12, P67.P$1, R147.2
unnamed: R158.1, U1.48 (CSI_REXT)
unnamed: D010.+, D012.2, L5.2, U11.1 (1-SW)
unnamed: C96.1, C97.1, D013.2, L4.2, U16.1 (1_SW)
unnamed: R164.2, U15.3 (CE)
unnamed: R165.2, U16.4 (4_EN)
unnamed: C96.2, D014.1, D015.2
unnamed: C93.2, R166.1, R167.2, U16.3 (3_FB)
unnamed: J13.1, J13.1-1 (1), P43.P$1, R171.1
unnamed: J16.1, J16.1-1 (1), P42.P$1, R170.1
unnamed: C98.1, D015.1, R172.2
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

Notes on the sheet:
I=6.8/R
Limit current 520mA
ESP32-P4
USB_TypeC *2 & TypeA
DC-DC:5V to 3V3
DC-DC:3V3 to 1V2
ESP32-P4_POWER
USB to UART
POWER
PHY
TypeA Limit Current
Relay
Ultrasonic Sensor
LIGHT SENSOR
I2C
ADD:0X5C
2.7V-4.2V
ADDRESS:0x5C
ADDRESS:1011100
LED
Temperature & Humidity(DHT20)
3V-5.5V
ADDRESS:0X38
PIR
Servo Motor
Accelerometer & Gyro
ADD:0X6B
HALL SENSOR
Custom_key
TTP223
Touch Sensor
GAS-MQ2
开关控制热释电功能的开启或关闭
SD card
MIC
Audio_Interface
CSI_Interface
I led=200mV/1.1=182mA
DSI_LED Driver
LDO:5V/3.3V to 1V8

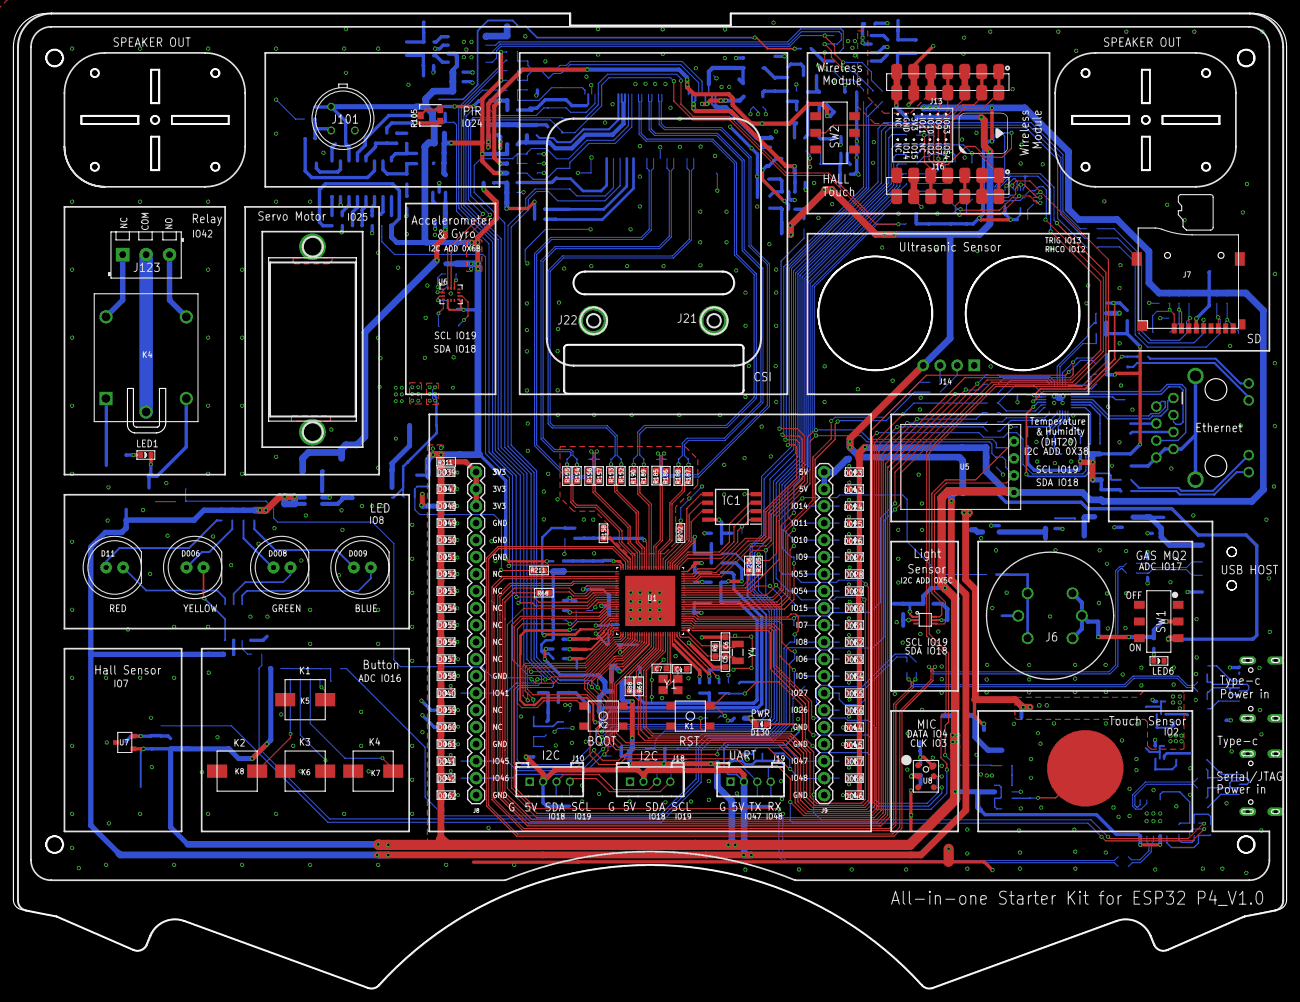
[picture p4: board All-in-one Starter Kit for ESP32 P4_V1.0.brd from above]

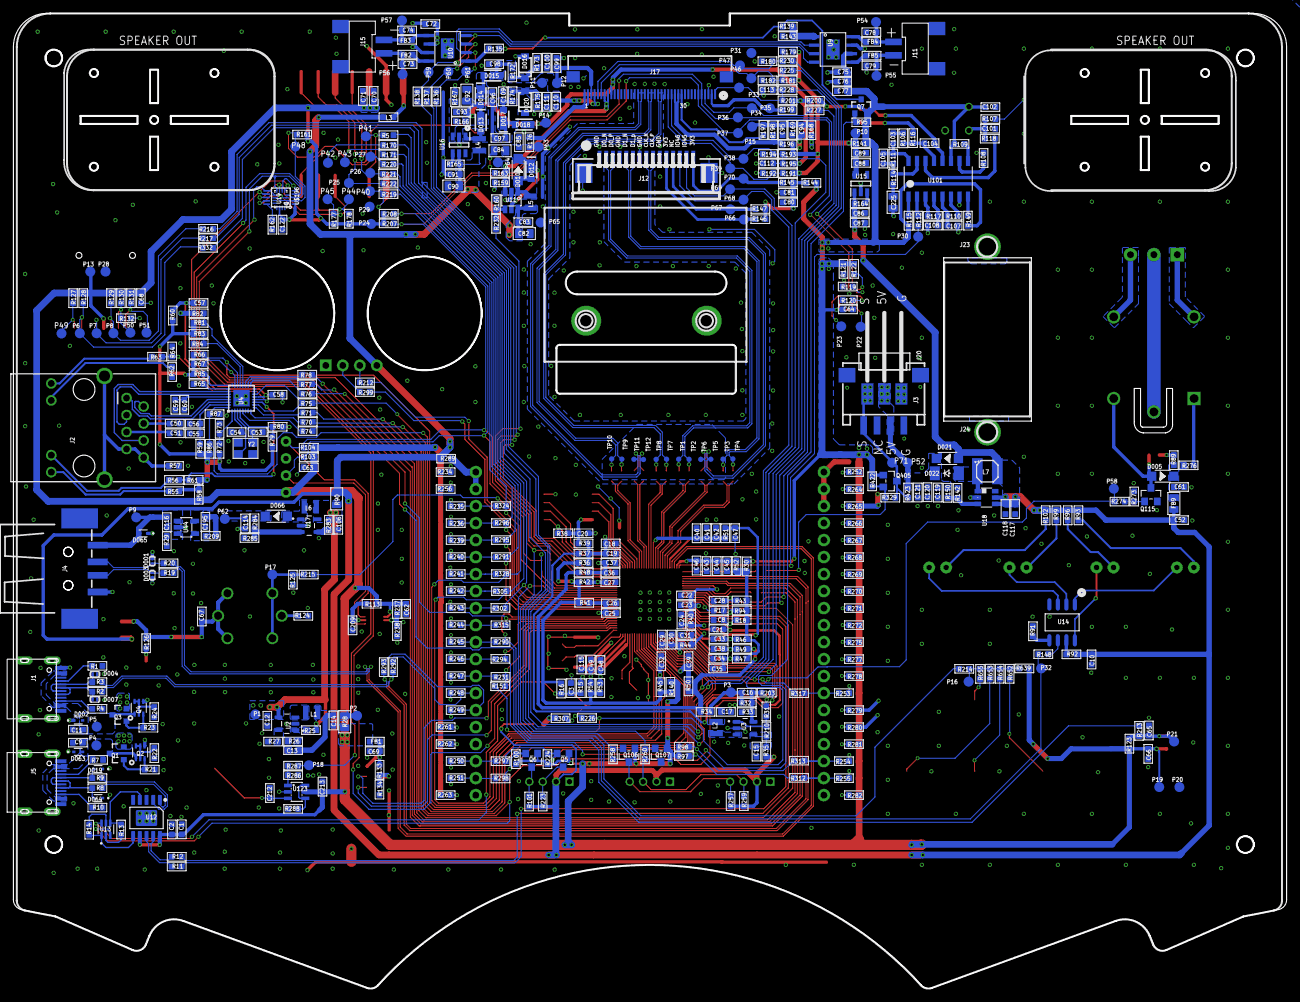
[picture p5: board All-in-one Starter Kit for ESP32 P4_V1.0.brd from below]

Board: 2 copper layers, 190.2 x 145.7 mm, 678 parts (571 on the bottom side), 399 nets.

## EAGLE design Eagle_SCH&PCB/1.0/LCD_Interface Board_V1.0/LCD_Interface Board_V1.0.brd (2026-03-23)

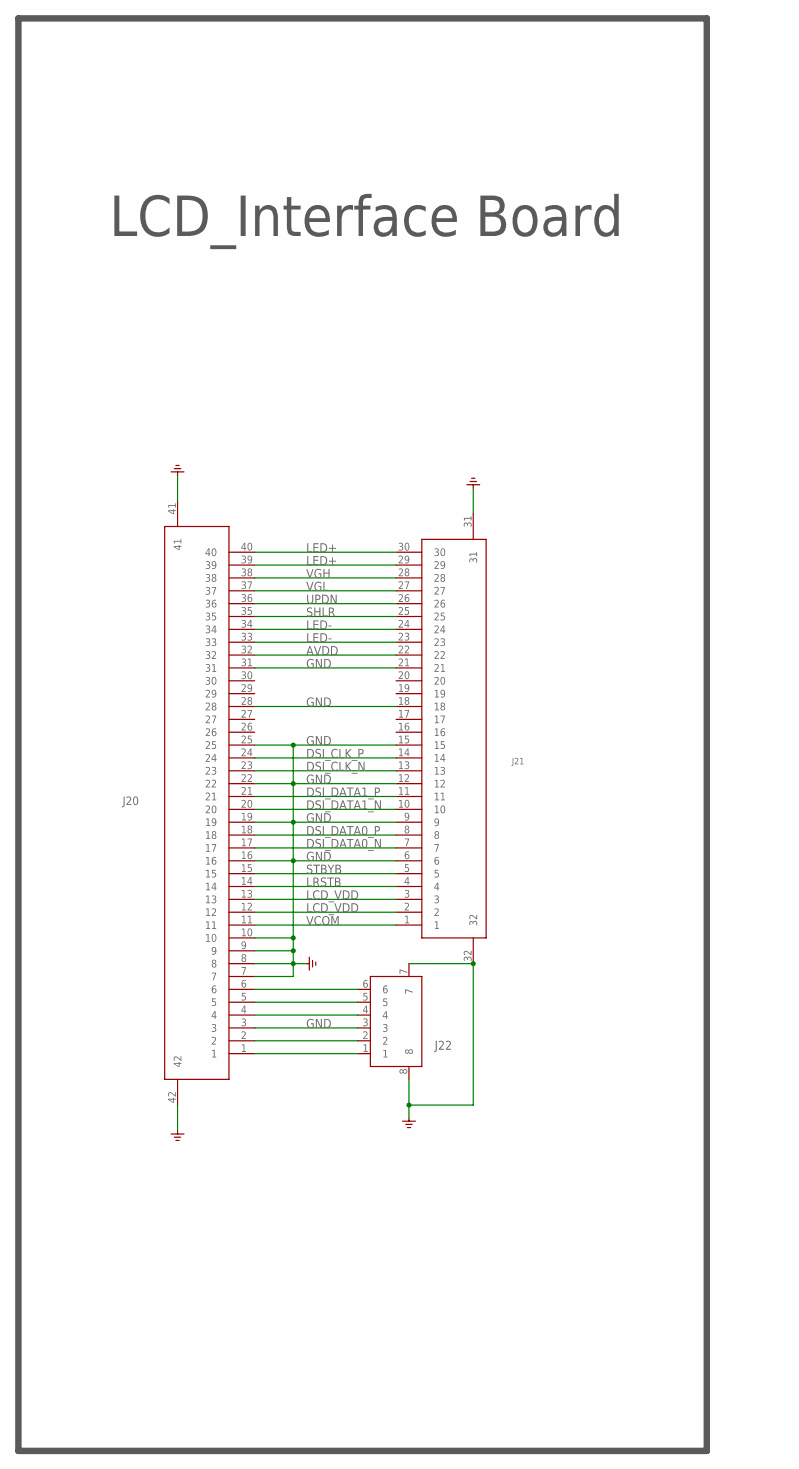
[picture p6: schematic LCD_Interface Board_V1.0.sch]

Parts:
J20: C19273935_40P_0.5MM_下接_HC-FPC-0.5-40P-FH20
J21: C23398852_30P_0.5MM_下接_FC-05A30P11H20
J22: C2856814_6P_0.5MM_下接_FPC-05F-6PH15

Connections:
AVDD: J20.32, J21.22
DSI_CLK_N: J20.23, J21.13
DSI_CLK_P: J20.24, J21.14
DSI_DATA0_N: J20.17, J21.7
DSI_DATA0_P: J20.18, J21.8
DSI_DATA1_N: J20.20, J21.10
DSI_DATA1_P: J20.21, J21.11
GND: J20.3, J20.7, J20.8, J20.9, J20.10, J20.16, J20.19, J20.22, J20.25, J20.28, J20.31, J20.41, J20.42, J21.6, J21.9, J21.12, J21.15, J21.18, J21.21, J21.31, J21.32, J22.3, J22.7, J22.8
LCD_VDD: J20.12, J20.13, J21.2, J21.3
LED+: J20.39, J20.40, J21.29, J21.30
LED-: J20.33, J20.34, J21.23, J21.24
LRSTB: J20.14, J21.4
unnamed: J20.6, J22.6
unnamed: J20.5, J22.5
unnamed: J20.4, J22.4
unnamed: J20.2, J22.2
unnamed: J20.1, J22.1
SHLR: J20.35, J21.25
STBYB: J20.15, J21.5
UPDN: J20.36, J21.26
VCOM: J20.11, J21.1
VGH: J20.38, J21.28
VGL: J20.37, J21.27

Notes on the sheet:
LCD_Interface Board

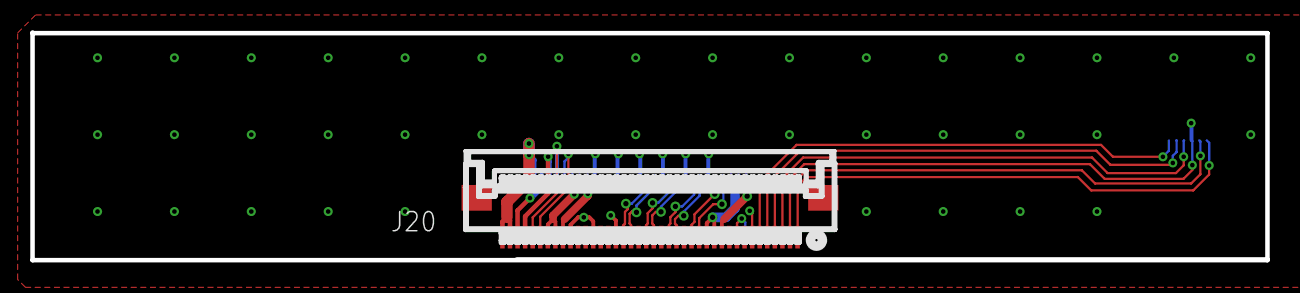
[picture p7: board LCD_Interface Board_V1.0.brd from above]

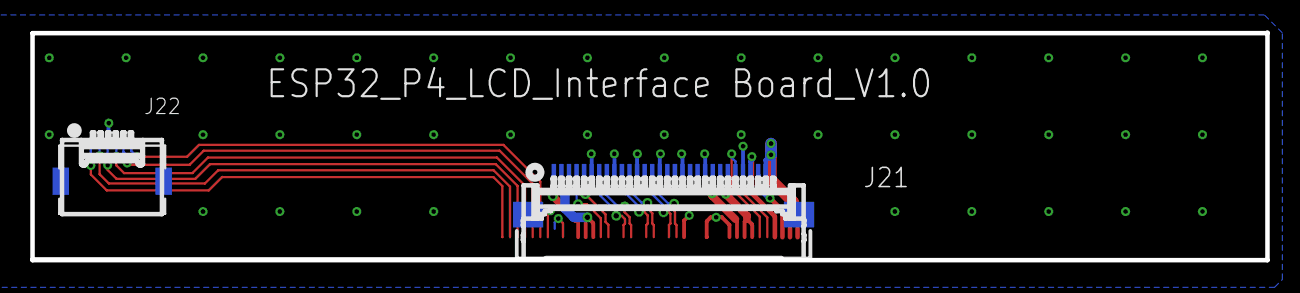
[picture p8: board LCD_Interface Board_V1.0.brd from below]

Board: 2 copper layers, 81.6 x 15.0 mm, 3 parts (2 on the bottom side), 23 nets.

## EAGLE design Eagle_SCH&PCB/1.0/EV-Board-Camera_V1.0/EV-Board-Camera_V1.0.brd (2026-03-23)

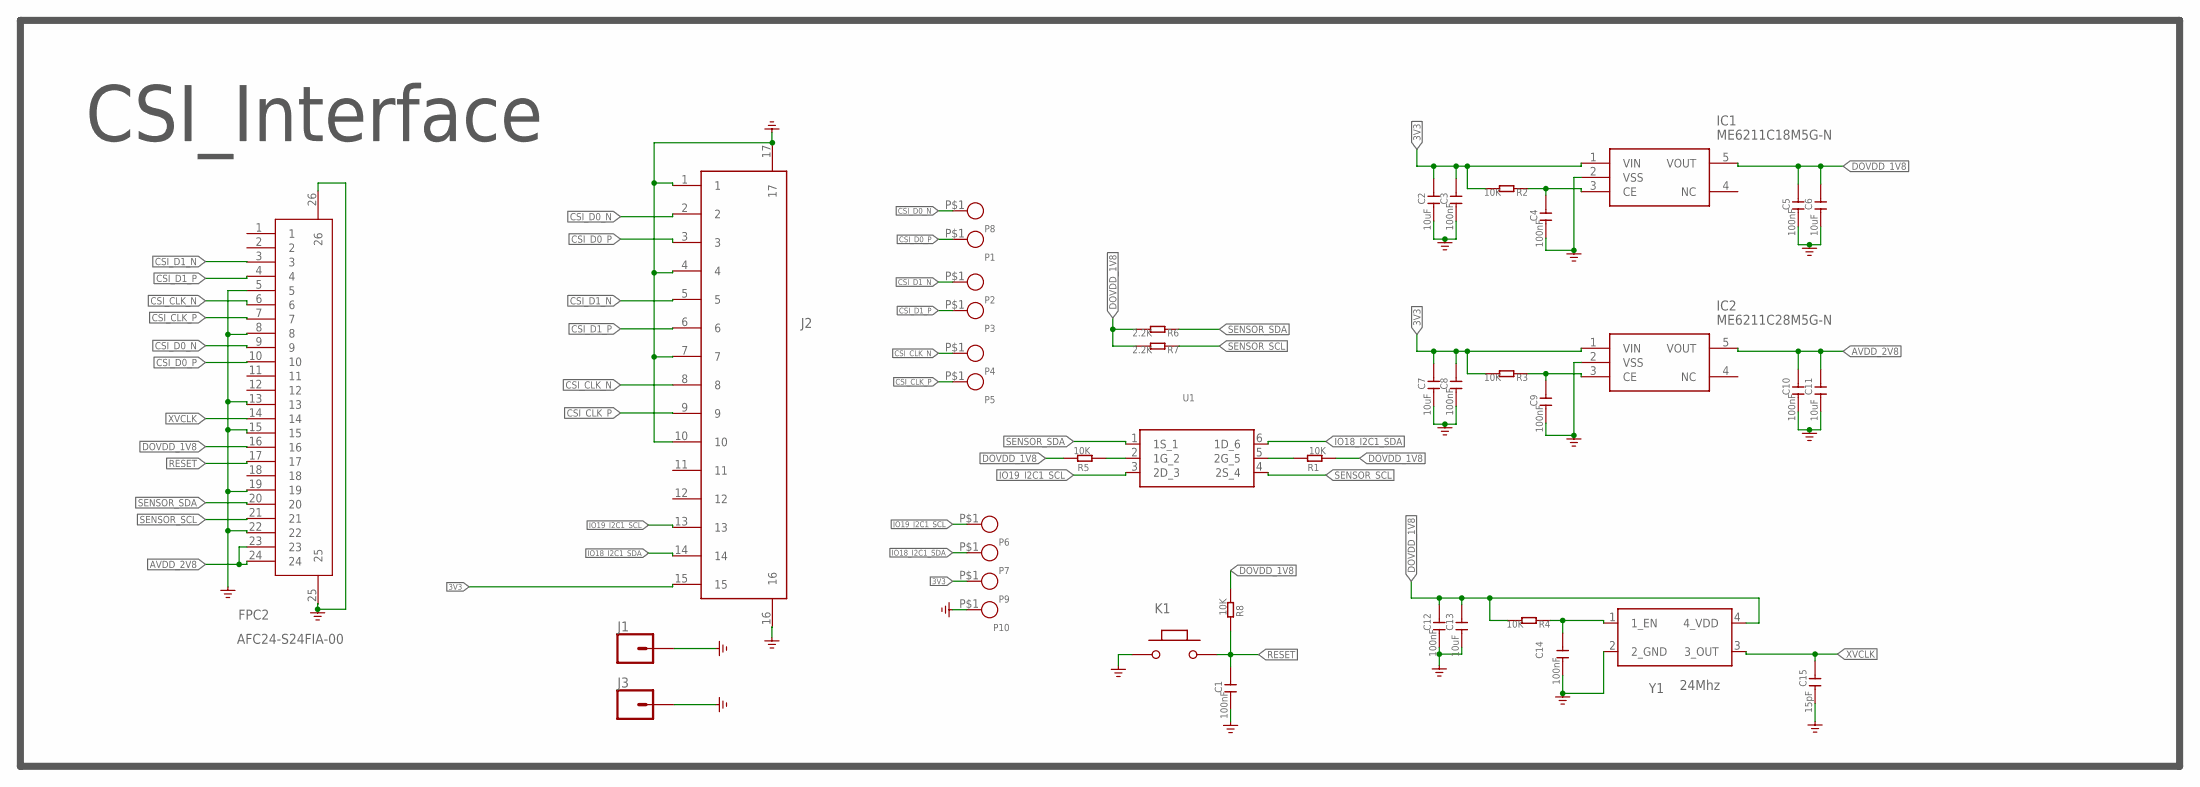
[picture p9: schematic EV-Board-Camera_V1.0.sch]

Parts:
C1, C3, C4, C5, C8, C9, C10, C12, C14: 100nF; C0402
C2, C6, C7, C11, C13: 10uF; C0402
C15: 15pF; C0402
FPC2: AFC24-S24FIA-00; FPC-SMD_P0.50-24P_QCHF-SM-H2.0
IC1: ME6211C18M5G-N; SOT95P282X145-5N
IC2: ME6211C28M5G-N; SOT95P282X145-5N
J1, J3: CONN_01_3.1MM_SMD1X01_3.1MM_SMD; 1X01_2MM
J2: C262349_15P_1MM_下接_AFA07-S15FCC-00
K1: BUTTON; 157SW
P1, P2, P3, P4, P5, P6, P7, P8, P9, P10: TEST_PADPAD-1.5MM; TEST_PAD-1.5MM
R1, R2, R3, R4, R5, R8: 10K; R0402
R6, R7: 2.2K; R0402
U1: WST2006
Y1: 24Mhz; 24MHZ_1631-24003-BTKEYA

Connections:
3V3: C2.2, C3.2, C7.2, C8.2, IC1.1 (VIN), IC2.1 (VIN), J2.15, P9.P$1, R2.2, R3.2
AVDD_2V8: C10.2, C11.2, FPC2.23, FPC2.24, IC2.5 (VOUT)
CSI_CLK_N: FPC2.6, J2.8, P4.P$1
CSI_CLK_P: FPC2.7, J2.9, P5.P$1
CSI_D0_N: FPC2.9, J2.2, P8.P$1
CSI_D0_P: FPC2.10, J2.3, P1.P$1
CSI_D1_N: FPC2.3, J2.5, P2.P$1
CSI_D1_P: FPC2.4, J2.6, P3.P$1
DOVDD_1V8: C5.2, C6.2, C12.2, C13.2, FPC2.16, IC1.5 (VOUT), R1.1, R4.2, R5.2, R6.2, R7.2, R8.1, Y1.4 (4_VDD)
GND: C1.1, C2.1, C3.1, C4.1, C5.1, C6.1, C7.1, C8.1, C9.1, C10.1, C11.1, C12.1, C13.1, C14.1, C15.1, FPC2.5, FPC2.8, FPC2.13, FPC2.15, FPC2.19, FPC2.22, FPC2.25, FPC2.26, IC1.2 (VSS), IC2.2 (VSS), J1.1, J2.1, J2.4, J2.7, J2.10, J2.16, J2.17, J3.1, K1.1, P10.P$1, Y1.2 (2_GND)
IO18_I2C1_SDA: J2.14, P7.P$1, U1.6 (1D_6)
IO19_I2C1_SCL: J2.13, P6.P$1, U1.3 (2D_3)
unnamed: R5.1, U1.2 (1G_2)
unnamed: C4.2, IC1.3 (CE), R2.1
unnamed: R1.2, U1.5 (2G_5)
unnamed: C9.2, IC2.3 (CE), R3.1
unnamed: C14.2, R4.1, Y1.1 (1_EN)
RESET: C1.2, FPC2.17, K1.2, R8.2
SENSOR_SCL: FPC2.21, R7.1, U1.4 (2S_4)
SENSOR_SDA: FPC2.20, R6.1, U1.1 (1S_1)
XVCLK: C15.2, FPC2.14, Y1.3 (3_OUT)

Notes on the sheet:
CSI_Interface

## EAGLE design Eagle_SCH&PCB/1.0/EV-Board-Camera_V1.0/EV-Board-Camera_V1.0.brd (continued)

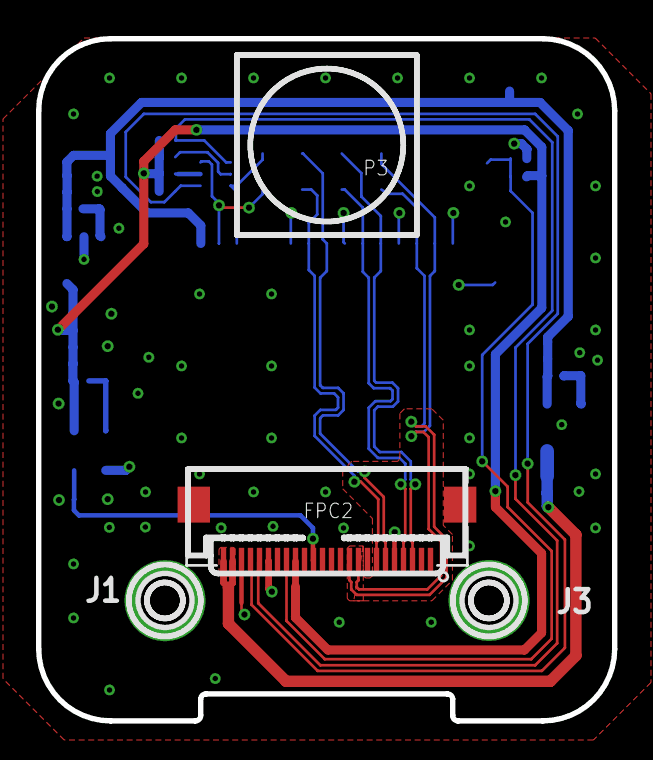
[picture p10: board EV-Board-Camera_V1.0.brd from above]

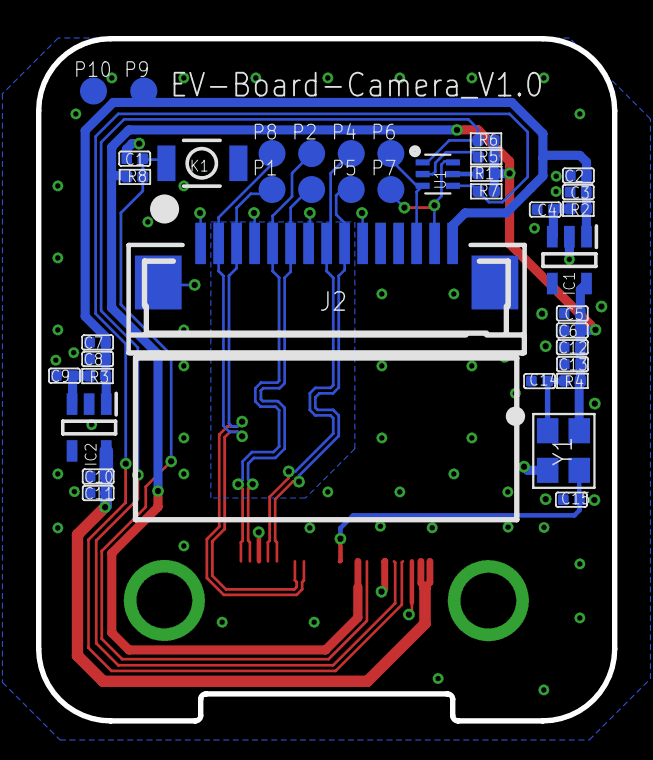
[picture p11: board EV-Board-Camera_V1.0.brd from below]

Board: 2 copper layers, 32.0 x 37.9 mm, 42 parts (39 on the bottom side), 21 nets.

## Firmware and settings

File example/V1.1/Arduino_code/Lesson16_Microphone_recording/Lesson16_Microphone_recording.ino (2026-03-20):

#include <Arduino.h>
#include <FS.h>
#include <SD_MMC.h>          // Depending on SD card type, SD.h can also be used
#include <ESP_I2S.h>         // Provides I2SClass definition
#include <esp_ldo_regulator.h>  // ESP32-P4 specific LDO management
#include <sys/unistd.h>         // Include system calls for file handling
#include <sys/stat.h>           // Include functions for file status and permissions
#include <esp_vfs_fat.h>        // Include ESP-IDF FAT filesystem support for SD card
#include <sdmmc_cmd.h>          // Include SDMMC card command definitions and helpers
#include <driver/sdmmc_host.h>  // Include SDMMC host driver for SD card communication

// ========== Pin definitions (modify according to your wiring) ==========

#pragma once

#define AUDIO_GPIO_CTRL         (30)    // GPIO pin number for audio power
#define AUDIO_POWER_ENABLE      (LOW)   // GPIO set low level to enable audio power
#define AUDIO_POWER_DISABLE     (HIGH)  // GPIO set high level to disable audio power

#define MIC_GPIO_CLK            (3)    // GPIO pin number for microphone BCLK (Bit Clock of PDM)
#define MIC_GPIO_SDIN           (4)    // GPIO pin number for microphone SDIN (Serial Data of PDM)

// SD card GPIO with SD_MMC
#define SD_GPIO_MMC_CLK     (43)
#define SD_GPIO_MMC_CMD     (44)
#define SD_GPIO_MMC_D0      (39)
// SD card GPIO with SPI
#define SD_GPIO_SPI_CLK     SD_GPIO_MMC_CLK
#define SD_GPIO_SPI_MOSI    SD_GPIO_MMC_CMD
#define SD_GPIO_SPI_MISO    SD_GPIO_MMC_D0

// ========== Recording parameters ==========
#define SAMPLE_RATE      16000        // Sample rate 16kHz
#define RECORD_SECONDS   5            // Recording duration (seconds)
#define BYTE_RATE        (SAMPLE_RATE * 16 / 8) // Bytes per second for 16-bit mono
#define BUFFER_SIZE      16000        // Buffer size for each read (bytes)

// ========== Global I2S object ==========
static I2SClass i2s_mic;             // I2S object for microphone input

// ========== Buffer ==========
uint8_t i2s_readraw_buff[BUFFER_SIZE];  // Temporary buffer to store I2S data

#define EXAMPLE_MAX_CHAR_SIZE 64   // Maximum character buffer size for file read/write operations
#define SD_MOUNT_POINT "/sdcard"   // Default SD card mount point path

static sdmmc_card_t *card;           // Pointer to SD card information
const char sd_mount_point[] = SD_MOUNT_POINT;

// Initialize ESP32-P4 LDO power rails for audio and peripheral devices
esp_err_t board_p4_ldo_init() 
{
    esp_err_t err = ESP_OK;
    esp_ldo_channel_handle_t ldo3_handle = NULL;
    esp_ldo_channel_config_t ldo3_cfg = {
        .chan_id = 3,           // LDO Channel 3
        .voltage_mv = 2500,     // Set to 2500mV (2.5V)
    };

    Serial.println("Initializing LDO3 to 2.5V...");
    err = esp_ldo_acquire_channel(&ldo3_cfg, &ldo3_handle); // Acquire LDO3 channel
    if (err != ESP_OK) {
        Serial.printf("LDO3 Power Error: %s\n", esp_err_to_name(err));
        return err;
    } else {
        Serial.println("LDO3 Power enabled successfully.");
    }
    
    // --- Power Configuration (LDO4 for I2C/touch pull up) ---
    esp_ldo_channel_handle_t ldo4_handle = NULL;
    esp_ldo_channel_config_t ldo4_cfg = {
        .chan_id = 4,           // LDO Channel 4
        .voltage_mv = 3300,     // Set to 3300mV (3.3V)
    };

    Serial.println("Initializing LDO4 to 3.3V...");
    err = esp_ldo_acquire_channel(&ldo4_cfg, &ldo4_handle); // Acquire LDO4 channel
    if (err != ESP_OK) {
        Serial.printf("LDO4 Power Error: %s\n", esp_err_to_name(err));
        return err;
    } else {
        Serial.println("LDO4 Power enabled successfully.");
    }

    return ESP_OK;
}

// ========== Generate WAV header ==========
void generate_wav_header(uint8_t *header, size_t data_size, uint32_t sample_rate) {
    // RIFF chunk descriptor
    memcpy(header, "RIFF", 4);
    uint32_t chunk_size = data_size + 36;
    memcpy(header + 4, &chunk_size, 4);
    memcpy(header + 8, "WAVE", 4);

    // fmt sub-chunk
    memcpy(header + 12, "fmt ", 4);
    uint32_t fmt_size = 16;
    memcpy(header + 16, &fmt_size, 4);
    uint16_t audio_format = 1;           // PCM
    memcpy(header + 20, &audio_format, 2);
    uint16_t num_channels = 1;           // Mono
    memcpy(header + 22, &num_channels, 2);
    memcpy(header + 24, &sample_rate, 4);
    uint32_t byte_rate = sample_rate * num_channels * 16 / 8;
    memcpy(header + 28, &byte_rate, 4);
    uint16_t block_align = num_channels * 16 / 8;
    memcpy(header + 32, &block_align, 2);
    uint16_t bits_per_sample = 16;       // 16-bit samples
    memcpy(header + 34, &bits_per_sample, 2);

    // data sub-chunk
    memcpy(header + 36, "data", 4);
    memcpy(header + 40, &data_size, 4);
}

// ========== Initialize I2S microphone (PDM mode) ==========
bool init_mic() {
    // Set GPIO pins for PDM receive mode
    i2s_mic.setPinsPdmRx(MIC_GPIO_CLK, MIC_GPIO_SDIN);
    
    // Begin I2S in PDM receive mode with 16kHz, 16-bit mono
    if (!i2s_mic.begin(I2S_MODE_PDM_RX, 16000, I2S_DATA_BIT_WIDTH_16BIT, I2S_SLOT_MODE_MONO, I2S_STD_SLOT_LEFT)) {
        Serial.println("PDM input initialization failed!");
        while (1) delay(1000);  // Halt execution on failure
    }
    
    return true;
}

// ========== Record audio and save as WAV to SD card ==========
int mic_read_to_sd(const char *filename, size_t rec_seconds, size_t *out_size) {
    if (rec_seconds > 3600 || filename == NULL) {
        return 1; // Invalid parameter
    }
    if (BUFFER_SIZE < 16000) {
        return 1; // Buffer too small
    }

    size_t rec_size = rec_seconds * BYTE_RATE;          // Total audio data size
    uint8_t wav_header[44];
    generate_wav_header(wav_header, rec_size, SAMPLE_RATE);

    // Open SD card file in binary write mode
    FILE *file = fopen(filename, "wb");
    if (!file) {
        Serial.println("Failed to open file for writing");
        return 2;
    }

    // Write WAV header
    if (fwrite(wav_header, 1, 44, file) != 44) {
        fclose(file);
        return 3;
    }

    size_t written_total = 0;
    while (written_total < rec_size) {
        size_t bytes_to_read = min((size_t)BUFFER_SIZE, rec_size - written_total);
        size_t bytes_read = 0;

        // Read bytes from I2S microphone
        bytes_read = i2s_mic.readBytes((char*)i2s_readraw_buff, bytes_to_read);
        if (bytes_read == 0) {
            Serial.println("I2S read failed");
            fclose(file);
            return 4;
        }

        // Seek to correct position in file (after WAV header)
        if (fseek(file, written_total + 44, SEEK_SET) != 0) {
            fclose(file);
            return 5;
        }

        // Write buffer data to file
        if (fwrite(i2s_readraw_buff, 1, bytes_read, file) != bytes_read) {
            fclose(file);
            return 6;
        }

        written_total += bytes_read; // Increment total written bytes
    }

    fclose(file);
    if (out_size != NULL) {
        *out_size = rec_size + 44;  // Return total file size including header
    }
    return 0;
}

// ========== Initialize SD card (SD_MMC mode) ==========
esp_err_t sd_init()
{
    esp_err_t err = ESP_OK;
    esp_vfs_fat_sdmmc_mount_config_t mount_config = {
        // If SD card file system is not FAT32, mount fails unless format_if_mount_failed=true
        .format_if_mount_failed = false,    
        .max_files = 5,
        .allocation_unit_size = 16 * 1024,
    };

    sdmmc_host_t host =  SDMMC_HOST_DEFAULT(); // Use default SDMMC host
    host.slot = SDMMC_HOST_SLOT_0;
    host.max_freq_khz = 10000;                // Limit clock frequency

    sdmmc_slot_config_t slot_config = SDMMC_SLOT_CONFIG_DEFAULT(); // Default slot config
    slot_config.clk = (gpio_num_t)SD_GPIO_MMC_CLK;
    slot_config.cmd = (gpio_num_t)SD_GPIO_MMC_CMD;
    slot_config.d0 = (gpio_num_t)SD_GPIO_MMC_D0;
    slot_config.width = 1;  // Use 1-line SDIO
    slot_config.flags |= SDMMC_SLOT_FLAG_INTERNAL_PULLUP; // Enable internal pull-ups

    // Mount SD card filesystem
    err = esp_vfs_fat_sdmmc_mount(sd_mount_point, &host, &slot_config, &mount_config, &card);
    if (err != ESP_OK) {
        if (err == ESP_FAIL) {
            Serial.println("Failed to mount filesystem.");
        } else {
            Serial.printf("Failed to initialize the card (%s).\n", esp_err_to_name(err));
        }
        return err;
    }
    Serial.println("SD card mounted successfully");
    sdmmc_card_print_info(stdout, card); // Print SD card info
    return err;
}

// ========== Arduino main program ==========
void setup() {
    Serial.begin(115200);               // Initialize Serial for debugging
    board_p4_ldo_init();                // Initialize LDO power rails
    // Initialize SD card (using SD_MMC mode, 1-line data)
    if (sd_init() != ESP_OK) {
        Serial.println("SD card initialization failed!");
        return;
    }
    
    // Initialize microphone
    if (!init_mic()) {
        Serial.println("Mic initialization failed");
        return;
    }
    
    // Start recording 5 seconds
    Serial.println("Start recording...");
    size_t total_size;
    int ret = mic_read_to_sd("/sdcard/test.wav", RECORD_SECONDS, &total_size);
    if (ret == 0) {
        Serial.printf("Recording finished, file size: %u bytes\n", total_size);
    } else {
        Serial.printf("Recording failed, error code: %d\n", ret);
    }
    
    // Stop I2S interface
    i2s_mic.end();
}

void loop() {
    // Empty loop, user can add other tasks here
}

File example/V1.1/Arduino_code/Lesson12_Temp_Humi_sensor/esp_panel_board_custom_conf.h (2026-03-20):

/*
 * SPDX-FileCopyrightText: 2023-2025 Espressif Systems (Shanghai) CO LTD
 *
 * SPDX-License-Identifier: Apache-2.0
 */
/**
 * @file   esp_panel_board_custom_conf.h
 * @brief  Configuration file for custom ESP development boards
 * @author
 * @link
 *
 * This file contains all the configurations needed for a custom board using ESP Panel.
 * Users can modify these configurations according to their hardware design.
 */

#pragma once

// *INDENT-OFF*

/**
 * @brief Flag to enable custom board configuration (0/1)
 *
 * Set to `1` to enable custom board configuration, `0` to disable
 */
#define ESP_PANEL_BOARD_DEFAULT_USE_CUSTOM  (1)

#if ESP_PANEL_BOARD_DEFAULT_USE_CUSTOM
////////////////////////////////////////////////////////////////////////////////////////////////////////////////////////
///////////////////////// Please update the following macros to configure general parameters ///////////////////////////
////////////////////////////////////////////////////////////////////////////////////////////////////////////////////////
/**
 * @brief Board name (format: "Manufacturer:Model")
 */
#define ESP_PANEL_BOARD_NAME                "Custom:Custom"

/**
 * @brief Panel resolution configuration in pixels
 */
#define ESP_PANEL_BOARD_WIDTH               (1024)   // Panel width (horizontal, in pixels)
#define ESP_PANEL_BOARD_HEIGHT              (600)   // Panel height (vertical, in pixels)

////////////////////////////////////////////////////////////////////////////////////////////////////////////////////////
//////////////////////////// Please update the following macros to configure the LCD panel /////////////////////////////
////////////////////////////////////////////////////////////////////////////////////////////////////////////////////////
/**
 * @brief LCD panel configuration flag (0/1)
 *
 * Set to `1` to enable LCD panel support, `0` to disable
 */
#define ESP_PANEL_BOARD_USE_LCD             (1)

#if ESP_PANEL_BOARD_USE_LCD
/**
 * @brief LCD controller selection
 *
 * Supported controllers:
 * - `AXS15231B`
 * - `EK9716B`, `EK79007`
 * - `GC9A01`, `GC9B71`, `GC9503`
 * - `HX8399`
 * - `ILI9341`, `ILI9881C`
 * - `JD9165`, `JD9365`
 * - `NV3022B`
 * - `SH8601`
 * - `SPD2010`
 * - `ST7262`, `ST7701`, `ST7703`, `ST7789`, `ST7796`, `ST77903`, `ST77916`, `ST77922`
 */
#define ESP_PANEL_BOARD_LCD_CONTROLLER      EK79007

/**
 * @brief LCD bus type selection
 *
 * Supported bus types:
 * - `ESP_PANEL_BUS_TYPE_SPI`
 * - `ESP_PANEL_BUS_TYPE_QSPI`
 * - `ESP_PANEL_BUS_TYPE_RGB` (ESP32-S3 only)
 * - `ESP_PANEL_BUS_TYPE_MIPI_DSI` (ESP32-P4 only)
 */
#define ESP_PANEL_BOARD_LCD_BUS_TYPE        (ESP_PANEL_BUS_TYPE_MIPI_DSI)

#if (ESP_PANEL_BOARD_LCD_BUS_TYPE == ESP_PANEL_BUS_TYPE_SPI) || \
    (ESP_PANEL_BOARD_LCD_BUS_TYPE == ESP_PANEL_BUS_TYPE_QSPI)
/**
 * If set to 1, the bus will skip to initialize the corresponding host. Users need to initialize the host in advance.
 *
 * For drivers which created by this library, even if they use the same host, the host will be initialized only once.
 * So it is not necessary to set the macro to `1`. For other drivers (like `Wire`), please set the macro to `1`
 * ensure that the host is initialized only once.
 */
#define ESP_PANEL_BOARD_LCD_BUS_SKIP_INIT_HOST      (0)     // 0/1. Typically set to 0
#endif

/**
 * @brief LCD bus parameters configuration
 *
 * Configure parameters based on the selected bus type. Parameters for other bus types will be ignored.
 * For detailed parameter explanations, see:
 * https://docs.espressif.com/projects/esp-idf/en/v5.3.1/esp32s3/api-reference/peripherals/lcd/index.html
 * https://docs.espressif.com/projects/esp-iot-solution/en/latest/display/lcd/index.html
 */
#if ESP_PANEL_BOARD_LCD_BUS_TYPE == ESP_PANEL_BUS_TYPE_SPI

    /**
     * @brief SPI bus
     */
    /* For general */
    #define ESP_PANEL_BOARD_LCD_SPI_HOST_ID         (1)     // Typically set to 1
#if !ESP_PANEL_BOARD_LCD_BUS_SKIP_INIT_HOST
    /* For host */
    #define ESP_PANEL_BOARD_LCD_SPI_IO_SCK          (7)
    #define ESP_PANEL_BOARD_LCD_SPI_IO_MOSI         (6)
    #define ESP_PANEL_BOARD_LCD_SPI_IO_MISO         (-1)    // -1 if not used
#endif // ESP_PANEL_BOARD_LCD_BUS_SKIP_INIT_HOST
    /* For panel */
    #define ESP_PANEL_BOARD_LCD_SPI_IO_CS           (5)     // -1 if not used
    #define ESP_PANEL_BOARD_LCD_SPI_IO_DC           (4)
    #define ESP_PANEL_BOARD_LCD_SPI_MODE            (0)     // 0-3. Typically set to 0
    #define ESP_PANEL_BOARD_LCD_SPI_CLK_HZ          (40 * 1000 * 1000)
                                                            // Should be an integer divisor of 80M, typically set to 40M
    #define ESP_PANEL_BOARD_LCD_SPI_CMD_BITS        (8)     // Typically set to 8
    #define ESP_PANEL_BOARD_LCD_SPI_PARAM_BITS      (8)     // Typically set to 8
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

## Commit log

2026-03-20 add arduino
    [ESP32-P4 Display 9.0 inch V1.0.brd, ESP32-P4 Display 9.0 inch V1.0.sch, partitions.csv]
2026-05-22 sync idf lesson20
    [partitions.csv]

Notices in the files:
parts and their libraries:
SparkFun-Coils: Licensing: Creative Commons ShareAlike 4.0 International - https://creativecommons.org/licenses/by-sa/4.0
